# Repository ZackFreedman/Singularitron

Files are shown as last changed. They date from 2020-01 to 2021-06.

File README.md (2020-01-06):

# Singularitron
## Ridiculous VFD-equipped modular cyberwatch

More info at the [Singularitron's Hackaday.io page.](https://hackaday.io/project/169343-singularitron-modular-cyberwatch)

The Singularitron is a massive wrist-mounted wearable device with four expansion slots. Equip any combination of flashlight, laser, IR thermometer, environmental, and SD card modules, and stun the crowd with RGB buttons. The ultra-bright, extremely breakable VFD adds bright-daylight readability... and style.

Real talk, this does work, but is not intended to be a serious project. A VFD is a terrible choice for a wearable, and many parts of the project are suboptimal, ridiculous, and/or barely functional. Also, I made a bunch of boo-boos on the board and fixed them with airwires. I'll fix that some time, maybe.

That said, it serves its purpose - drawing attention at Meetups and conferences - really well. The cartridge form-factor is pretty cool, and this has neat super-small implementations of some interesting parts. Have fun!

If you really do want to build this, there are a lot of gotchas:

* I'll add them
* Eventually
* Right here

Copyright 2017 Zack Freedman

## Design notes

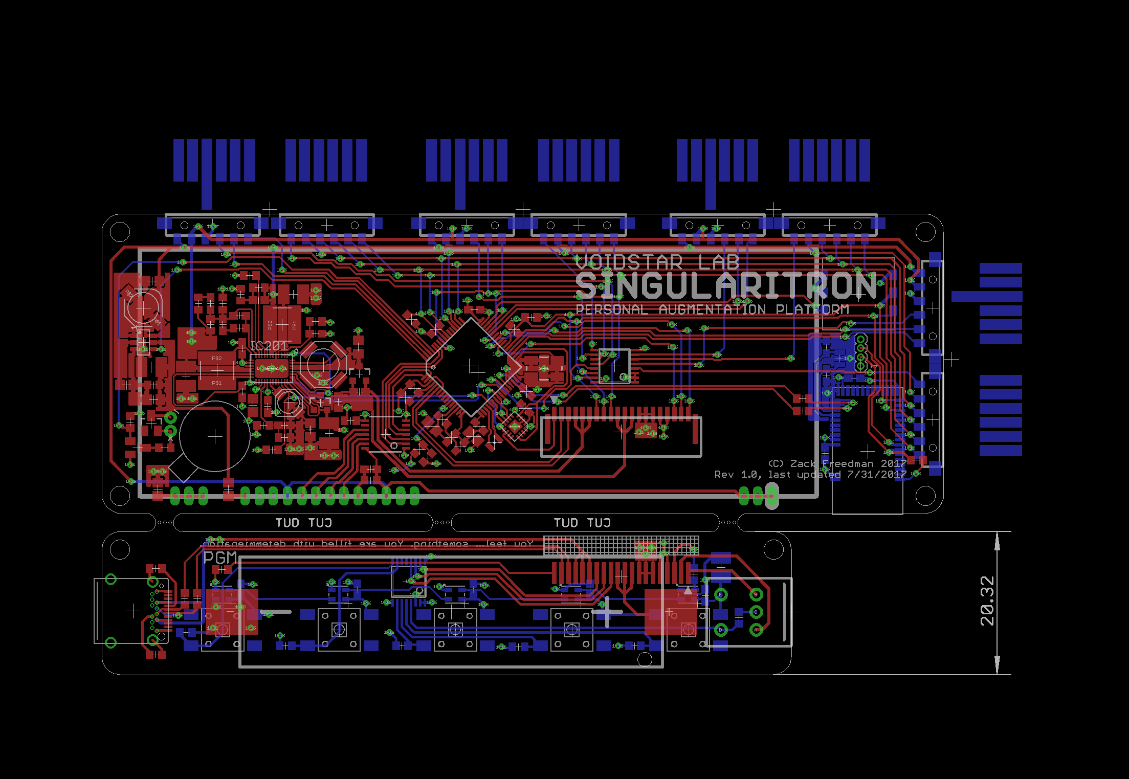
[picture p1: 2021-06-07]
Main PCB's/Singularitron Main Board Design.png

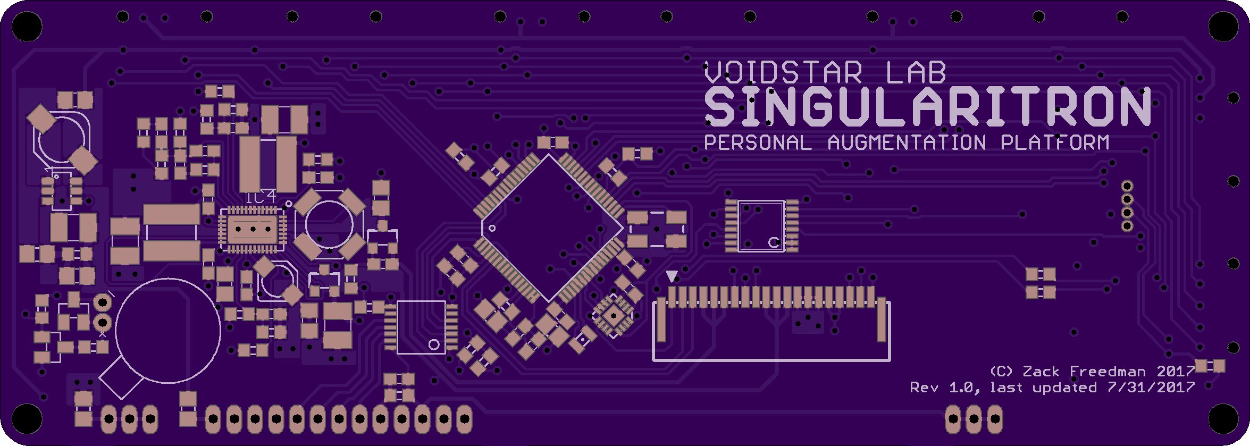
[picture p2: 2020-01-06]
Main PCB's/Singularitron 1B Mainboard Bottom Rendering.png

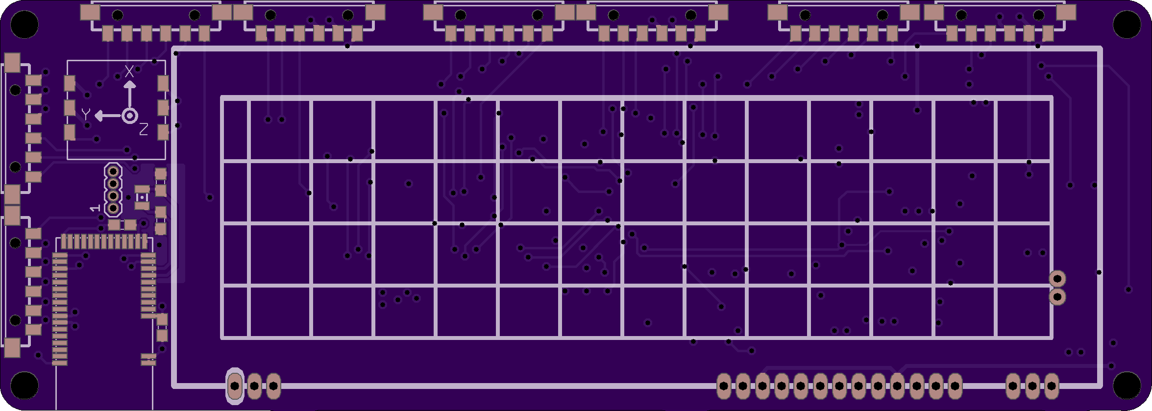
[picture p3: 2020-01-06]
Main PCB's/Singularitron 1B Main Board Rendering.png

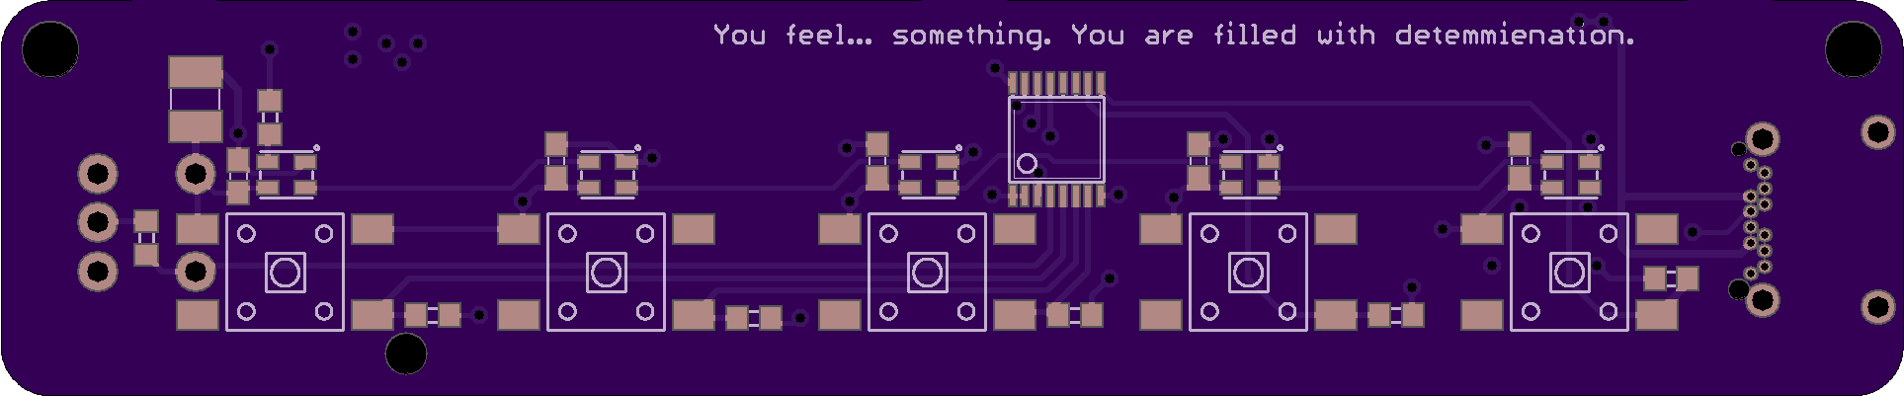
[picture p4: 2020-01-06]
Main PCB's/Singularitron 1B DB Top Rendering.png

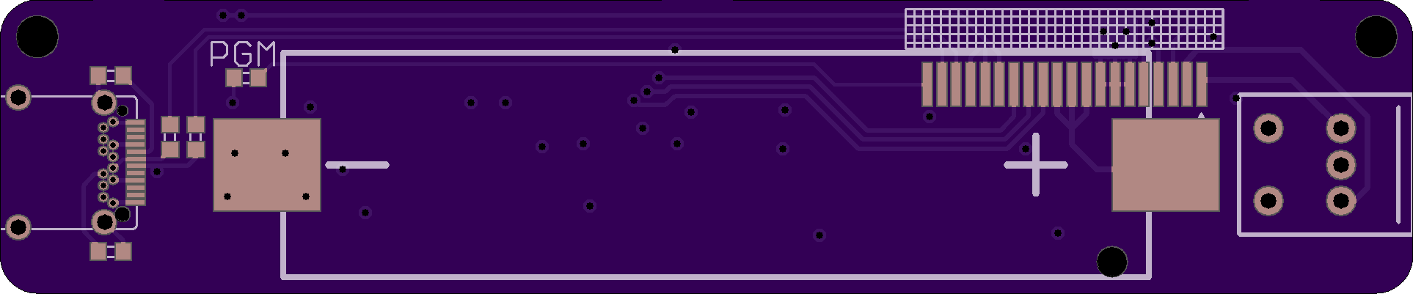
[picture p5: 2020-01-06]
Main PCB's/Singularitron 1B DB Bottom Rendering.png

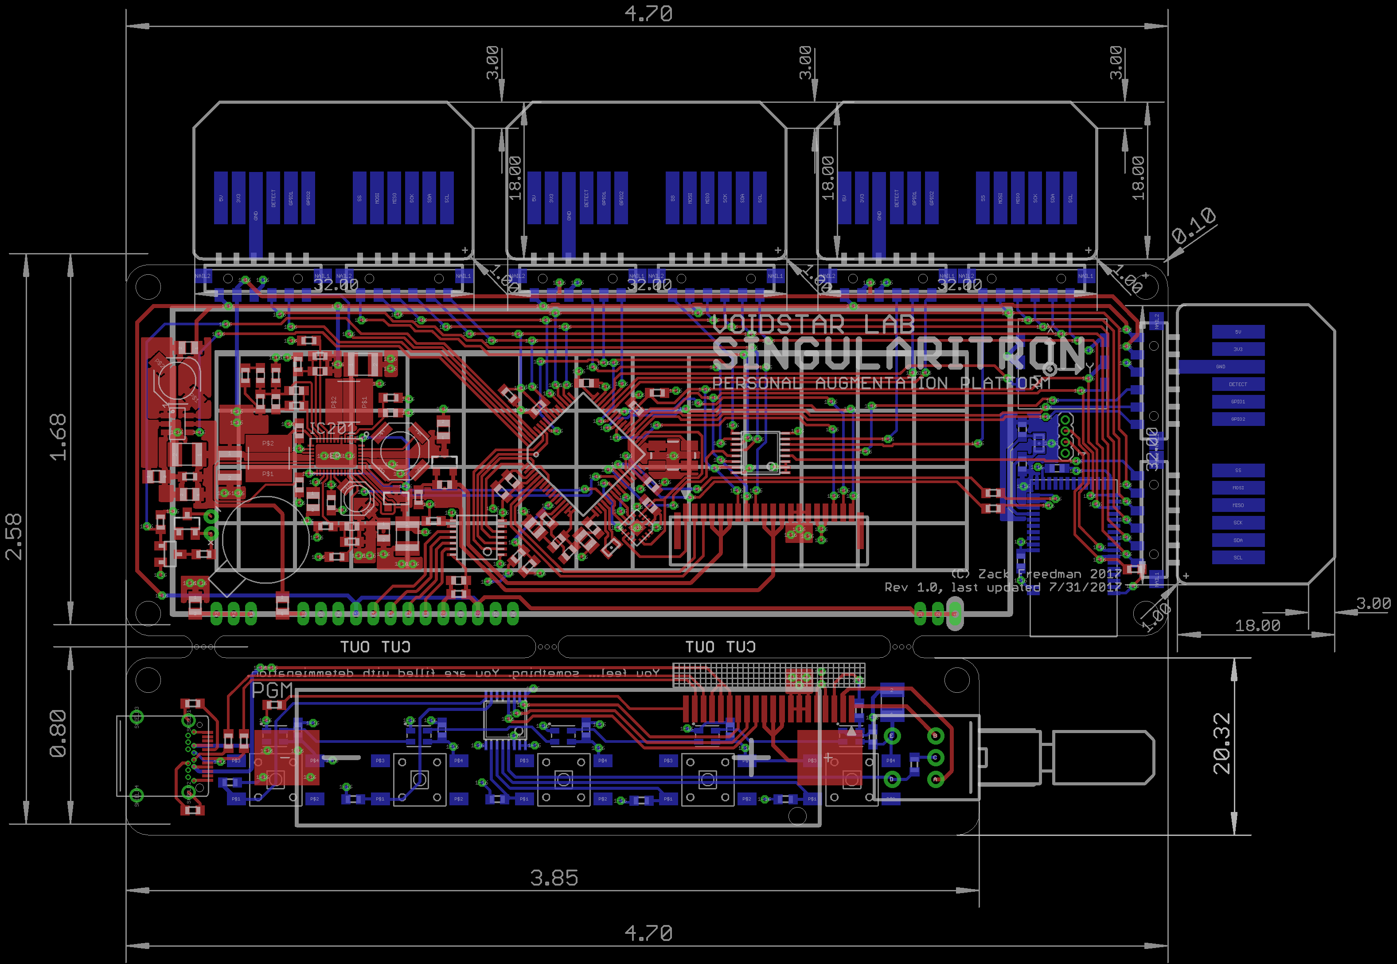
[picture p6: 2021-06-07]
Main PCB's/Singularitron Board.png

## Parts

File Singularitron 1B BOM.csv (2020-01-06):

Qty | Value | Device | Package | Parts | Description
1 |  | FFC_1MM_20POS_DIRECT | FFC_1MM_20POS_DIRECT | JP701 | 1mm-pitch, 20-position FFC glued and soldered directly to the PCB.
1 |  | M041.27MM | 1X04-1.27MM | JP401 | Header 4
1 |  | TXB0104PWR | TSSOP14 | U301 | 4-Bit Bi-Directional Level Shifter
1 | 0.01µF | C-USC0603 | C0603 | C301 | CAPACITOR, American symbol
12 | 0.1µF | C-USC0603 | C0603 | C213, C601, C602, C603, C604, C607, C608, C802, C803, C804, C805, C806 | CAPACITOR, American symbol
1 | 0.47µH | C-USC1210 | C1210 | C217 | CAPACITOR, American symbol
1 | 100nF | C-USC0603 | C0603 | C201 | CAPACITOR, American symbol
1 | 100Ω | R-US_R0603 | R0603 | R812 | RESISTOR, American symbol
2 | 105kΩ | R-US_R0603 | R0603 | R205, R215 | RESISTOR, American symbol
10 | 10kΩ | R-US_R0603 | R0603 | R207, R210, R301, R405, R806, R807, R808, R809, R810, R811 | RESISTOR, American symbol
1 | 10kΩ 0.1% 250mW | R-US_R0805 | R0805 | R213 | RESISTOR, American symbol
3 | 10pF | C-USC0603 | C0603 | C206, C207, C214 | CAPACITOR, American symbol
3 | 10µF | C-USC0805 | C0805 | C202, C203, C210 | CAPACITOR, American symbol
1 | 121kΩ | R-US_R0603 | R0603 | R216 | RESISTOR, American symbol
1 | 12401548E4#2A | 12401548E4#2A | 12401548E4#2A | CN801 | Amphenol USB C receptacle, surface-mount and through-hole pins
1 | 12kΩ | R-US_R0603 | R0603 | R401 | RESISTOR, American symbol
2 | 12pF | C-USC0603 | C0603 | C403, C404 | CAPACITOR, American symbol
1 | 15kΩ | R-US_R0603 | R0603 | R211 | RESISTOR, American symbol
1 | 16.9kΩ | R-US_R0603 | R0603 | R203 | RESISTOR, American symbol
1 | 16MHz | CRYSTAL-SHIELDED | CRYSTAL-SMD-5X3 | Y601
1 | 1MΩ | R-US_R0603 | R0603 | R801 | RESISTOR, American symbol
1 | 1kΩ | R-US_R0603 | R0603 | R208 | RESISTOR, American symbol
4 | 1µF | C-USC0603 | C0603 | C204, C205, C401, C402 | CAPACITOR, American symbol
1 | 1µF | C-USC0805 | C0805 | C212 | CAPACITOR, American symbol
3 | 2.2µF | C-USC0603 | C0603 | C211, C605, C606 | CAPACITOR, American symbol
2 | 2.2µH | CDRH4D22/HP | CDRH4D22/HP | L201, L205 | Sumida low-DCR shielded inductor
1 | 200kΩ | R-US_R0603 | R0603 | R302 | RESISTOR, American symbol
2 | 220Ω | R-US_R0603 | R0603 | R402, R403 | RESISTOR, American symbol
1 | 22pF | C-USC0805 | C0805 | C216 | CAPACITOR, American symbol
4 | 22µH | C-USC1210 | C1210 | C208, C209, C219, C801 | CAPACITOR, American symbol
1 | 22µH | SUMIDA_CDPH4D19F | CDPH4D19F | L204 | Low-profile shielded inductor, proprietary footprint, useful for low-current switching regulators
1 | 22Ω | R-US_R0603 | R0603 | R404 | RESISTOR, American symbol
1 | 22Ω 1/2W? | R-US_R0805 | R0805 | R303 | RESISTOR, American symbol
1 | 280kΩ 0.1% | R-US_R0603 | R0603 | R212 | RESISTOR, American symbol
1 | 3.01kΩ | R-US_R0603 | R0603 | R209 | RESISTOR, American symbol
1 | 3.3µH | CDRH6D12 | CDRH6D12 | L202 | Sumida low-profile shielded inductor
1 | 3.61kΩ | R-US_R0603 | R0603 | R206 | RESISTOR, American symbol
2 | 324kΩ | R-US_R0603 | R0603 | R204, R214 | RESISTOR, American symbol
1 | 32kHz | FC-12M | FC-12M | Q401 | kHz RANGE CRYSTAL UNIT
1 | 32kHz 12pF | FC-12M | FC-12M | Q601 | kHz RANGE CRYSTAL UNIT
1 | 330pF | C-USC0603 | C0603 | C215 | CAPACITOR, American symbol
1 | 33pF | C-USC0603 | C0603 | C218 | CAPACITOR, American symbol
2 | 33Ω | R-US_R0603 | R0603 | R803, R804 | RESISTOR, American symbol
4 | 4.7kΩ | R-US_R0603 | R0603 | R602, R603, R604, R605 | RESISTOR, American symbol
1 | 4.7µH | CDRH3D16/HP | CDRH3D16/HP | L203 | Sumida miniature low-profile shielded inductor
1 | 40kΩ | R-US_R0603 | R0603 | R201 | RESISTOR, American symbol
1 | 470Ω | R-US_R0603 | R0603 | R601 | RESISTOR, American symbol
2 | 5.1kΩ | R-US_R0603 | R0603 | R802, R805 | RESISTOR, American symbol
1 | 6.2Ω 1/2W | R-US_R0805 | R0805 | R304 | RESISTOR, American symbol
2 | 600Ω@100MHz | FERRITE-0603 | FB603 | L601, L602 | Ferrite bead in various packages
1 | 88.7kΩ | R-US_R0603 | R0603 | R202 | RESISTOR, American symbol
8 | AVX_9155066 | AVX_9155066 | 9155006 | CN501, CN502, CN503, CN504, CN505, CN506, CN507, CN508 | AVX 6-position 2mm pitch right-angle battery connector
1 | BAT54C | BAT54C | SOT23 | D401 | Schottky Diodes
1 | DS2045 | DS2045 | DS2045 | DISPLAY301
1 | EM7180SFP | EM7180SFP | EM7180SFP | MOD402 | EM7180SFP Sensor fusion platform module. Incorporated EM7180 Sentral Hub coprocessor, Bosch BMX055 9-DOF IMU, and ST24256 32KB EEPROM.
1 | HFW20R-1ST | HFW20R-1ST | HFW20R-1STE1LF | CN701 | Amphenol HF20R 20-contact 1mm-pitch FFC/FPC connector. No locking feature - friction only.
1 | KEYSTONE_1024 | KEYSTONE_1024 | KEYSTONE-1024-PROVISIONAL | BAT801
1 | LT3461A | LT3461A | SOT-23 | IC202 | Linear Technologies LT3461A 3MHz boost regulator, 16V max VIN, 38V max VOUT, 70mA output load current
1 | LTC3586-3 | LTC3586-3 | QFN-38_EP_UFE | IC201 | Linear LTC3586 PMIC
1 | MDBT40 | MDBT40 | MDBT40 | MOD401
1 | MK20DX128VLH5 | MK20DX128VLH5 | MK20DX128VLH5 | U601 | Teensy 3.0 Processing Unit - MK20DX128VLH5 ARM Cortex M0
1 | MKL02Z32VFG4 | MKL02Z32VFG4 | QFN16-3X3 | IC601
1 | MOTOR10MM | MOTOR10MM | VIBE-MOTOR-10MM | MOTOR401 | Vibration Motor- ROB-08449
5 | NEOPIXEL_NANO_2427 | NEOPIXEL_NANO_2427 | SK6805-2427 | LED801, LED802, LED803, LED804, LED805
1 | NVR4003NT3G | MOSFET-NREFLOW | SOT23 | Q402 | N-Channel Mosfet
2 | PCA9534PW | PCA9534PW | TSSOP16 | IC501, IC801 | 8-bit I2C-bus and SMBus low power I/O port with interrupt
1 | PEC09 | PEC09 | PEC09-2X20X-TXXXX | SW806 | Bourns low-profile rotary encoders
2 | SI2333DS-T1-E3 | MOSFET-PCHANNELSMD | SOT23-3 | Q201, Q202 | Generic PMOSFET
4 | SINGULARITRON_CART_BASE | SINGULARITRON_CART_BASE | SINGULARITRON_CART_BASE | JP501, JP502, JP503, JP504
5 | TACTILE_SWITCHTL3301-G | TACTILE_SWITCHTL3301-G | TL3301-X-FXXX-X-G | SW801, SW802, SW803, SW804, SW805

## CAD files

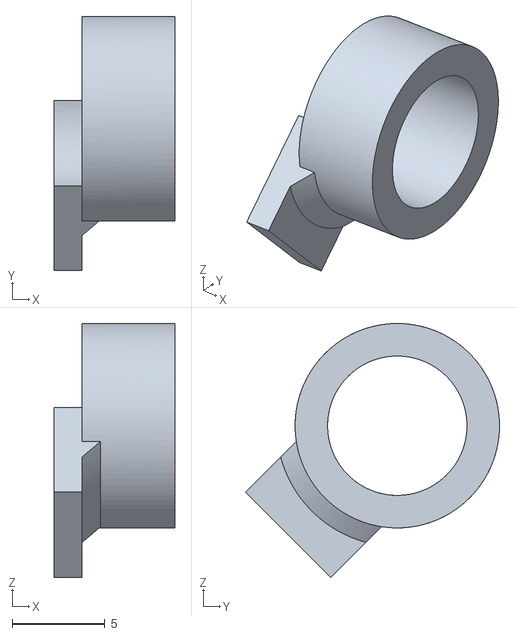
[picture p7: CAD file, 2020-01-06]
Enclosure/STL's/Singularitron Encoder Sleeve.stl
6.50 x 13.7 x 13.7

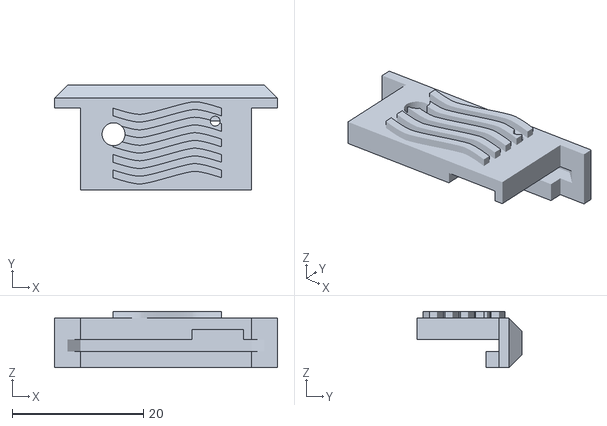
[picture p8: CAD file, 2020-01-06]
Modules/Enviro-Module/EnviroModule.stl
34.0 x 16.0 x 8.60

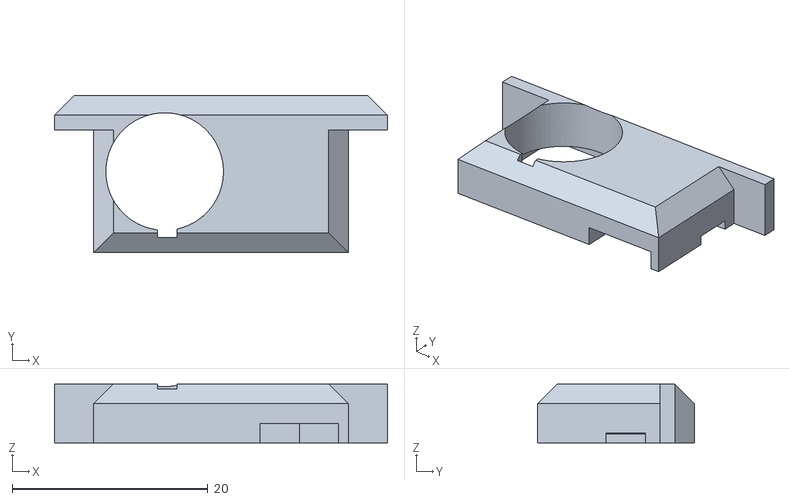
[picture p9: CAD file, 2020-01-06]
Modules/Flashlight Module/Flashlight Front.stl
34.0 x 16.0 x 6.00

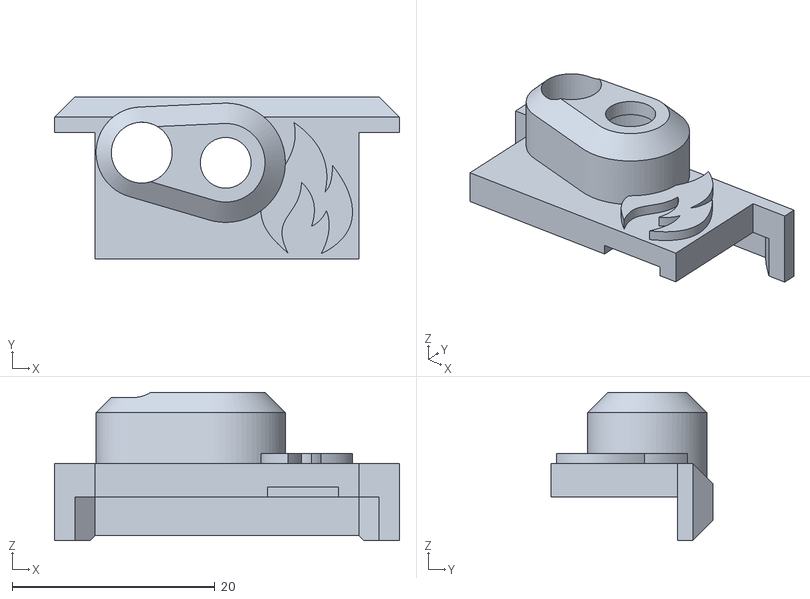
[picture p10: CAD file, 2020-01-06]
Modules/IR Thermometer Module/Thermodule.stl
34.0 x 16.0 x 14.6

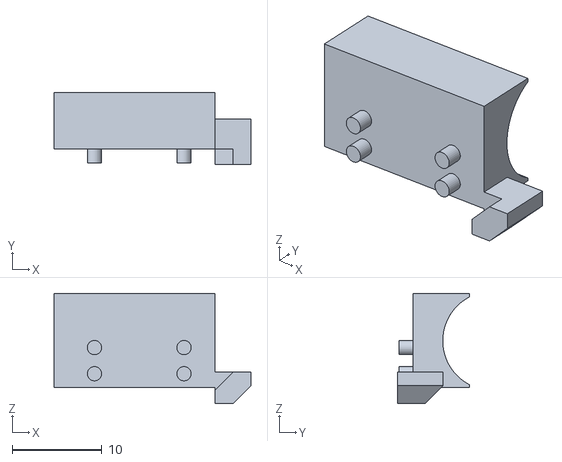
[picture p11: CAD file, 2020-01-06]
Modules/Laser Module/Laser Brace.stl
22.0 x 8.08 x 12.3

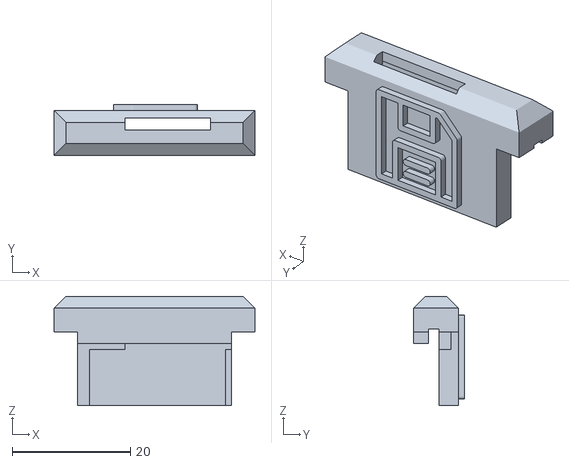
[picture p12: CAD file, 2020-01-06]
Modules/SD Card Module/SD Module.stl
34.0 x 8.60 x 18.5

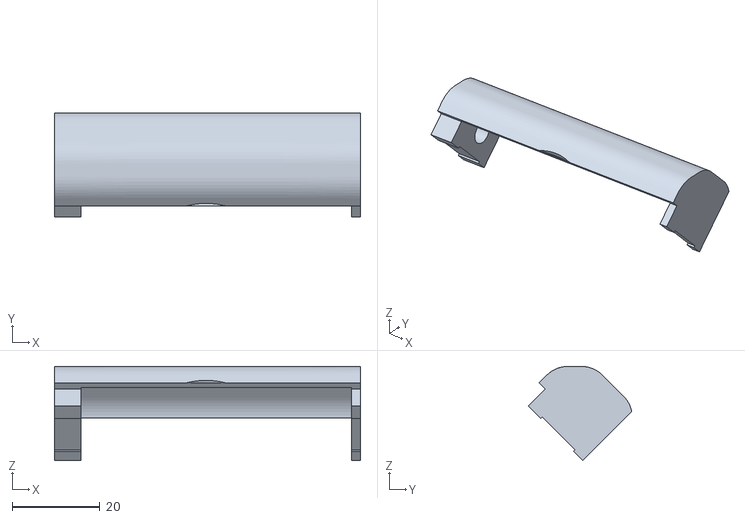
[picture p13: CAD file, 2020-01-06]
Enclosure/STL's/Singularitron Battery Lid.stl
69.8 x 23.6 x 21.5

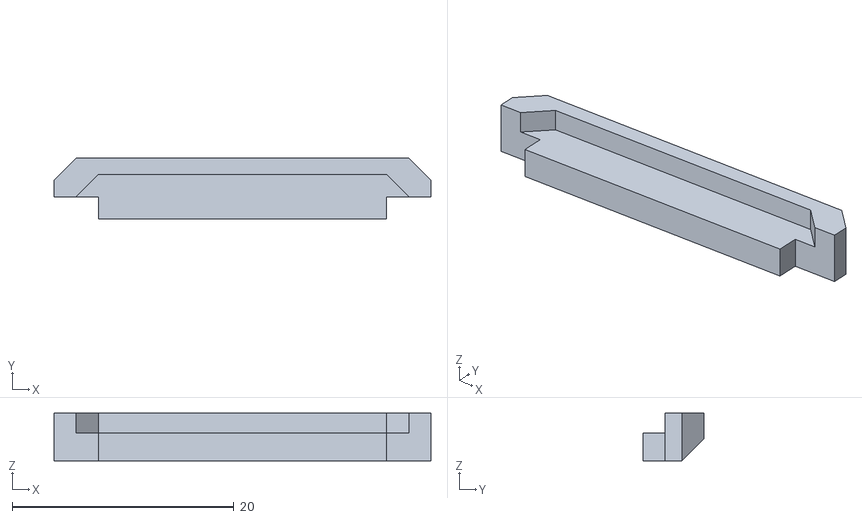
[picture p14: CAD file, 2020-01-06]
Modules/Flashlight Module/Flashlight Top.stl
34.0 x 5.50 x 4.30

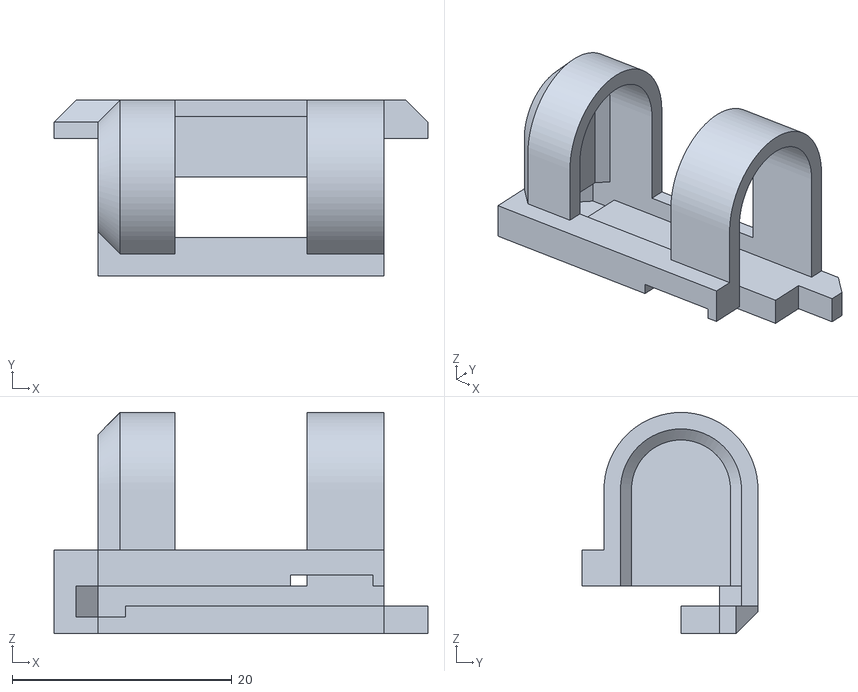
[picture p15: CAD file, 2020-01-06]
Modules/Laser Module/Laser Frame.stl
34.0 x 16.0 x 20.1

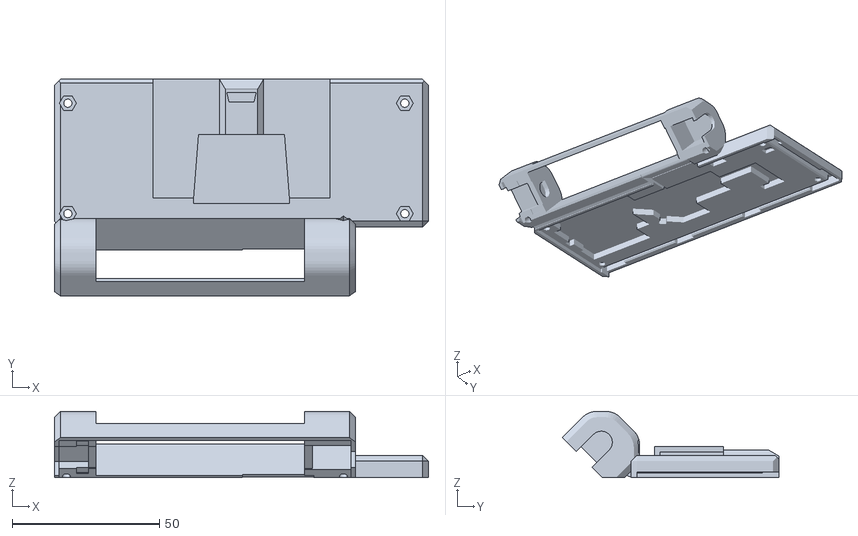
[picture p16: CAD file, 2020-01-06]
Enclosure/STL's/Singularitron Bottom.stl
126.9 x 73.5 x 22.5

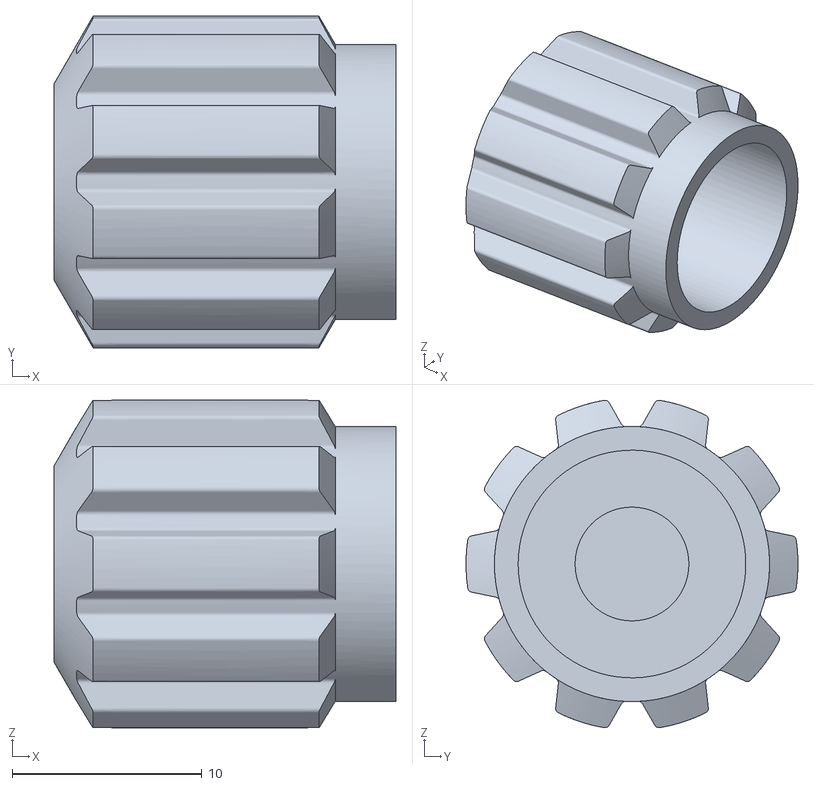
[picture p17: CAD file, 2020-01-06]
Enclosure/STL's/Singularitron Knob.stl
18.0 x 17.5 x 17.3

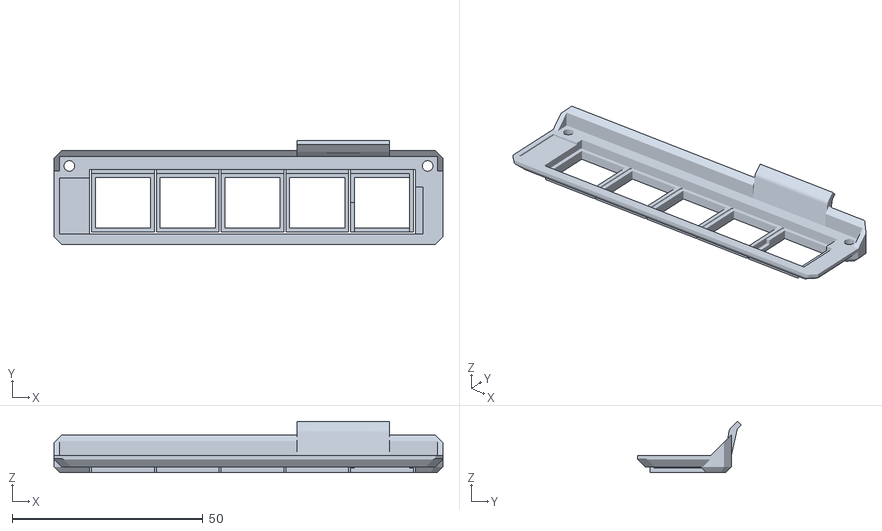
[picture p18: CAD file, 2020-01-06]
Enclosure/STL's/Singularitron Buttons.stl
102.1 x 27.2 x 13.5

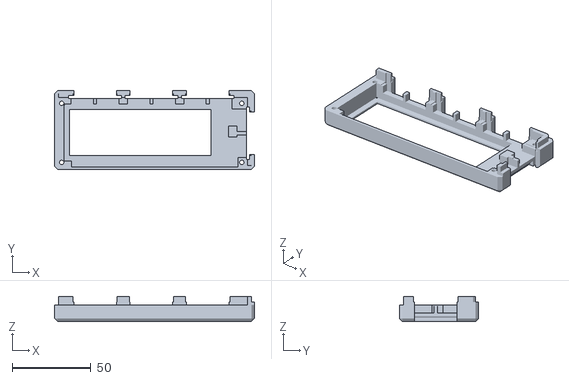
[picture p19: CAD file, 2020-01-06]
Enclosure/STL's/Singularitron Top.stl
126.9 x 50.2 x 16.0

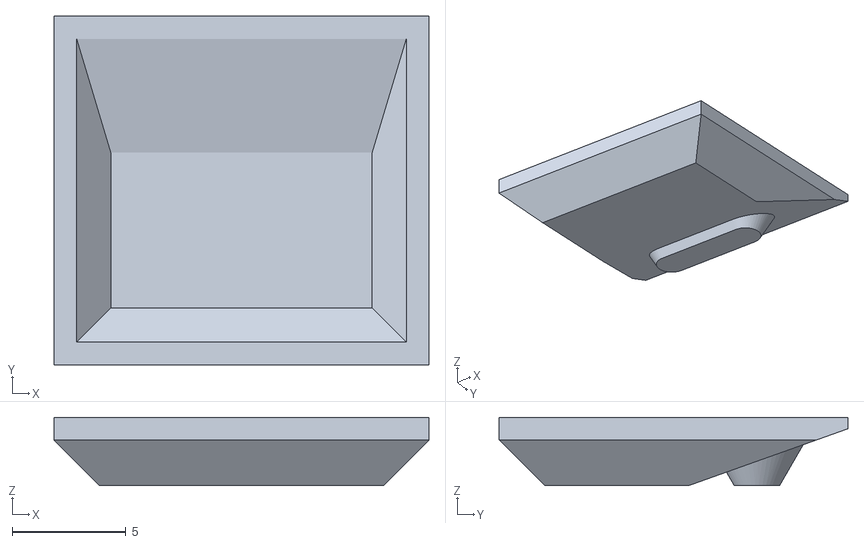
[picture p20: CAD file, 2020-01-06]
Enclosure/STL's/Keycap 0.stl
16.5 x 15.3 x 3.00

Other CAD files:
Enclosure/STL's/Keycap 1.stl
Enclosure/STL's/Keycap 2.stl
Enclosure/STL's/Keycap 3.stl
Enclosure/STL's/Keycap 4.stl
Enclosure/Overly Detailed Board Mockup.f3d
Enclosure/Singularitron Main.f3d
Modules/Enviro-Module/Enviro Module Cover Plate.f3d
Modules/Flashlight Module/Flashlight Module Cover Plate.f3d
Modules/IR Thermometer Module/Thermodule Cover.f3d
Modules/Laser Module/Laser Module Cover.f3d
Modules/SD Card Module/SD Module Cover Plate.f3d

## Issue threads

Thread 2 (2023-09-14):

Hola soy de latam

Aleemik, 2023-09-14:
Me encanta tu producto, aunque que es muy bobo, y poco fiable creo que sería genial tener uno en mi brazo, es demasiado increíble para muchas personas, compraría uno.

Sería genial que algún día lo vendas como un juguete curioso yo lo compraría. Estoy a la espera saludos y suerte.
Att Ale de Lima, Perú

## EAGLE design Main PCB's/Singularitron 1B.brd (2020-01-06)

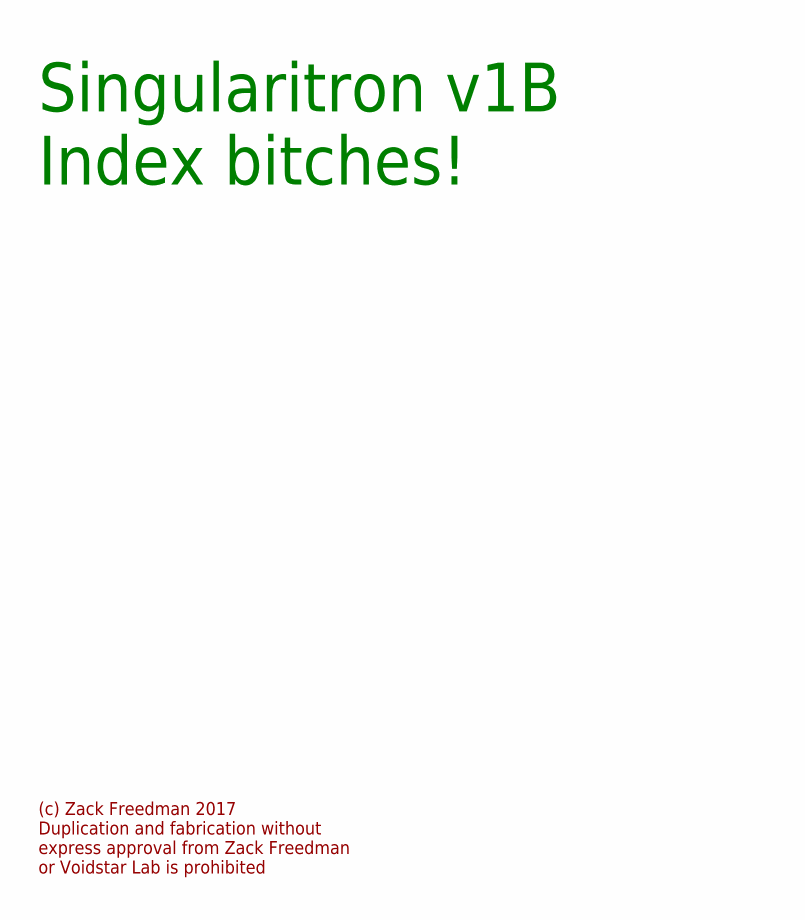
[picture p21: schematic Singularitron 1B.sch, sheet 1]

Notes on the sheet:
Singularitron v1B Index bitches!
(c) Zack Freedman 2017 Duplication and fabrication without express approval from Zack Freedman or Voidstar Lab is prohibited

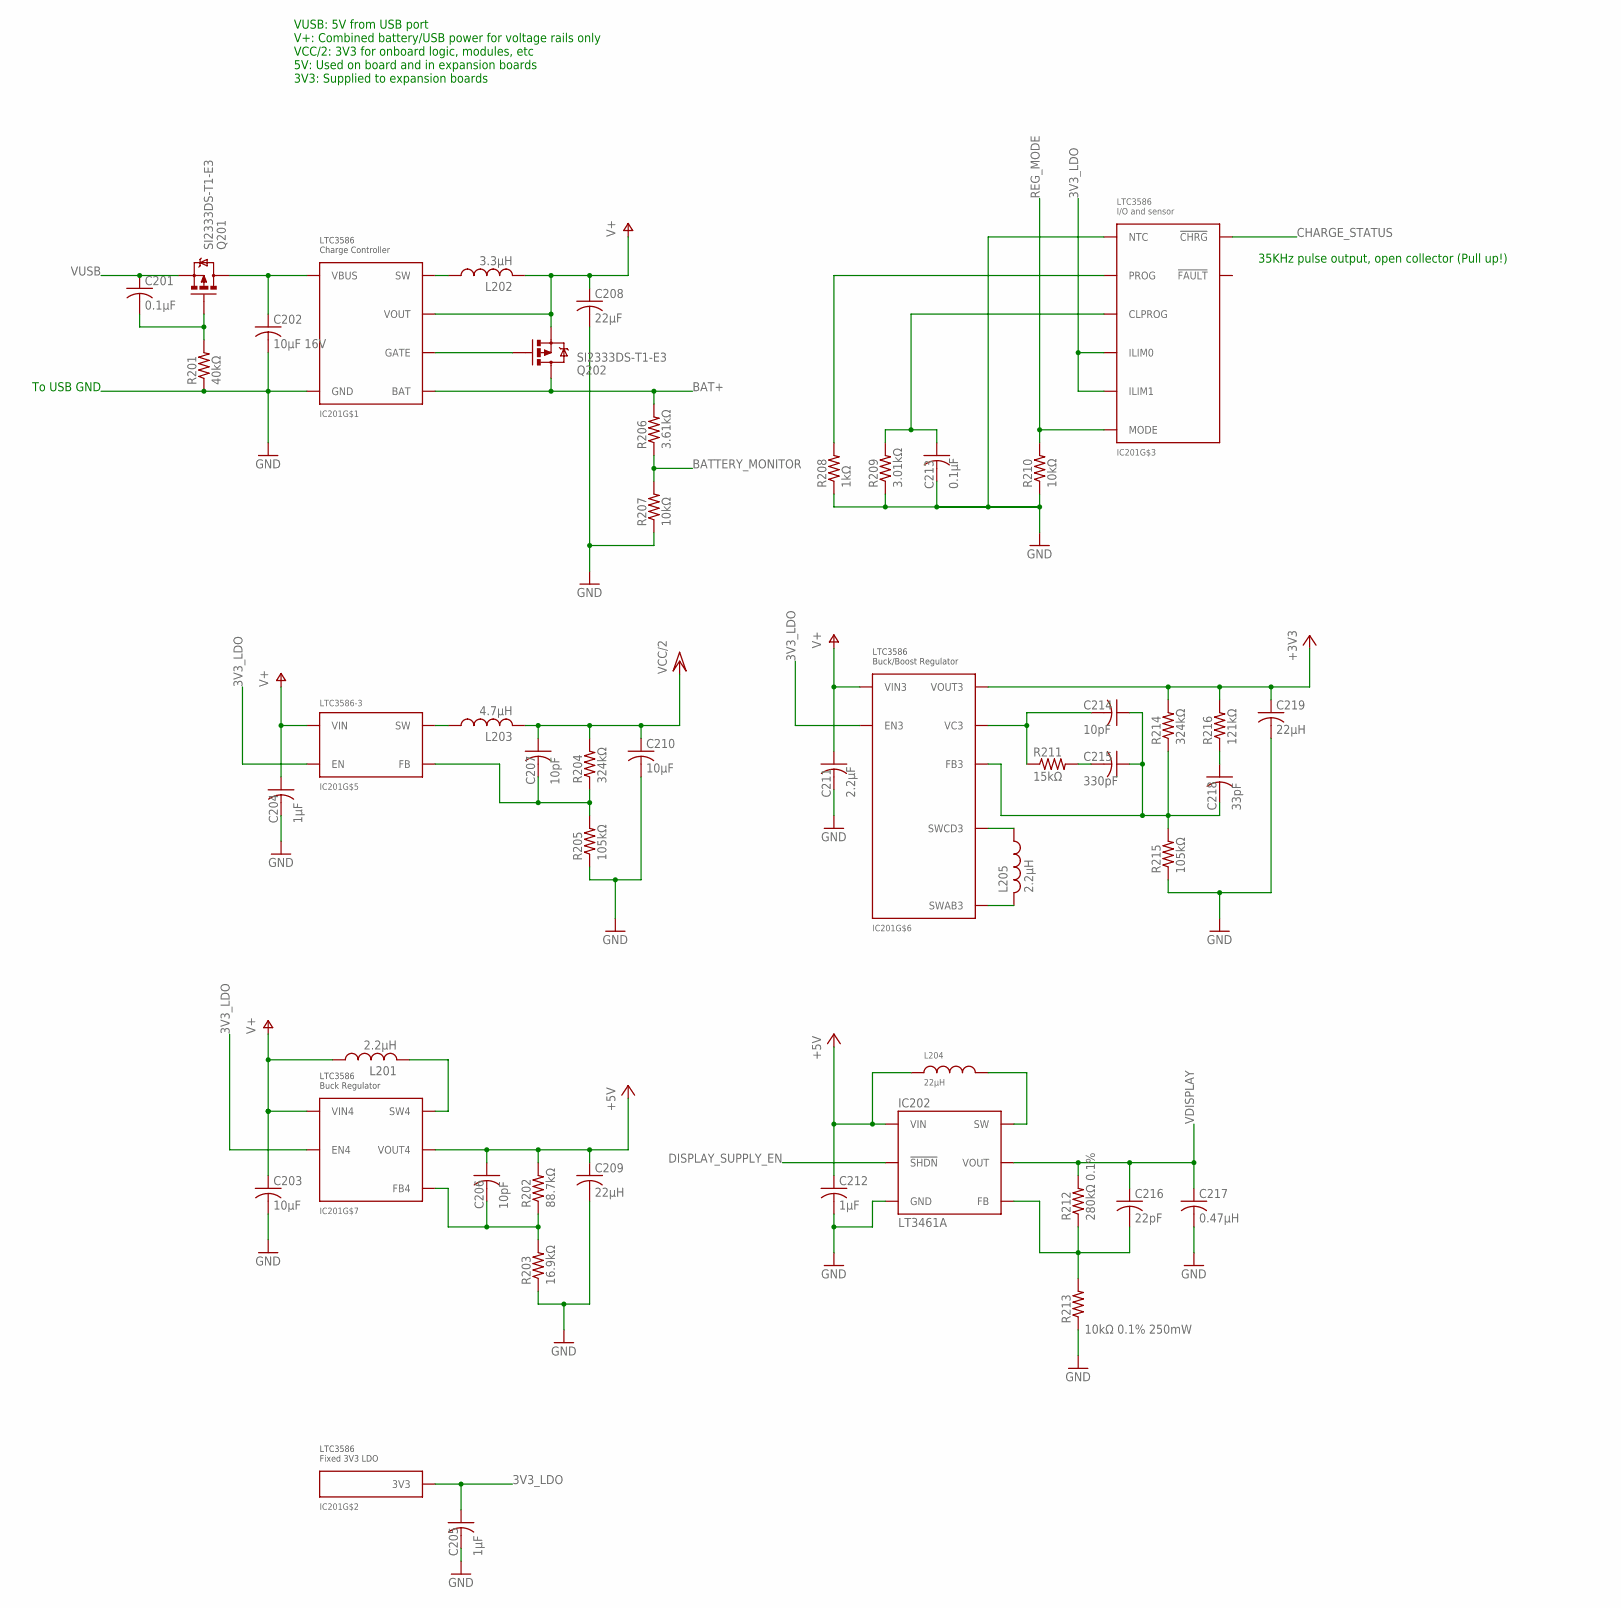
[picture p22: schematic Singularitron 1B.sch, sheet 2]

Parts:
C201, C213: 0.1µF; C0603
C202: 10µF 16V; C0805
C203, C210: 10µF; C0805
C204, C205: 1µF; C0603
C206, C207, C214: 10pF; C0603
C208: 22µF; C1210
C209, C219: 22µH; C1210
C211: 2.2µF; C0603
C212: 1µF; C0805
C215: 330pF; C0603
C216: 22pF; C0805
C217: 0.47µH; C1210
C218: 33pF; C0603
IC201: LTC3586-3; QFN-38_EP_UFE
IC202: LT3461A; SOT-23
L201, L205: 2.2µH; CDRH4D22/HP
L202: 3.3µH; CDRH6D12
L203: 4.7µH; CDRH3D16/HP
L204: 22µH; CDPH4D19F
Q201, Q202: SI2333DS-T1-E3; SOT23-3
R201: 40kΩ; R0603
R202: 88.7kΩ; R0603
R203: 16.9kΩ; R0603
R204, R214: 324kΩ; R0603
R205, R215: 105kΩ; R0603
R206: 3.61kΩ; R0603
R207, R210: 10kΩ; R0603
R208: 1kΩ; R0603
R209: 3.01kΩ; R0603
R211: 15kΩ; R0603
R212: 280kΩ 0.1%; R0603
R213: 10kΩ 0.1% 250mW; R0805
R216: 121kΩ; R0603

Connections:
3V3_LDO: C205.1, IC201.P$1 (ILIM0), IC201.P$2 (ILIM1), IC201.P$3 (3V3), IC201.P$18 (EN3), IC201.P$20 (EN), IC201.P$33 (EN4); also elsewhere on the board
+3V3: C219.1, IC201.P$16 (VOUT3), IC201.P$17 (VOUT3), R214.2, R216.2; also elsewhere on the board
+5V: C206.1, C209.1, C212.1, IC201.P$6 (VOUT4), IC201.P$7 (VOUT4), IC202.P6 (VIN), L204.P$1, R202.2; also elsewhere on the board
BAT+: IC201.P$32 (BAT), Q202.3 (D), R206.2; also elsewhere on the board
BATTERY_MONITOR: R206.1, R207.2; also elsewhere on the board
CHARGE_STATUS: IC201.P$30 (!CHRG); also elsewhere on the board
CLPROG: C213.1, IC201.P$4 (CLPROG), R209.2
DISPLAY_SUPPLY_EN: IC202.P4 (!SHDN); also elsewhere on the board
GND: C202.2, C203.2, C204.2, C205.2, C208.2, C209.2, C210.2, C211.2, C212.2, C213.2, C217.2, C219.2, IC201.EP (GND), IC201.P$5 (NTC), IC202.P2 (GND), R201.1, R203.1, R205.1, R207.1, R208.1, R209.1, R210.1, R213.1, R215.1; also elsewhere on the board
unnamed: C202.1, IC201.P$35 (VBUS), IC201.P$36 (VBUS), Q201.3 (D)
unnamed: IC201.P$37 (SW), L202.P$1 (1)
unnamed: C201.2, Q201.1 (G), R201.2
unnamed: IC201.P$31 (GATE), Q202.1 (G)
unnamed: IC201.P$25 (SW), L203.P$1 (1)
unnamed: IC201.P$29 (PROG), R208.2
unnamed: C207.2, IC201.P$23 (FB), R204.1, R205.2
unnamed: IC202.P1 (SW), L204.P$2
unnamed: C214.2, IC201.P$12 (VC3), R211.1
unnamed: C216.2, IC202.P3 (FB), R212.1, R213.2
unnamed: C215.2, R211.2
unnamed: IC201.P$8 (SW4), L201.P$2 (2)
unnamed: C218.1, R216.1
unnamed: C206.2, IC201.P$10 (FB4), R202.1, R203.2
unnamed: C214.1, C215.1, C218.2, IC201.P$11 (FB3), R214.1, R215.2
unnamed: IC201.P$19 (SWCD3), L205.P$1 (1)
unnamed: IC201.P$13 (SWAB3), L205.P$2 (2)
REG_MODE: IC201.P$9 (MODE), R210.2
V+: C203.1, C204.1, C208.1, C211.1, IC201.P$14 (VIN3), IC201.P$15 (VIN3), IC201.P$22 (VIN4), IC201.P$24 (VIN), IC201.P$34 (VOUT), L201.P$1 (1), L202.P$3 (2), Q202.2 (S)
VCC/2: C207.1, C210.1, L203.P$2 (2), R204.2; also elsewhere on the board
VDISPLAY: C216.1, C217.1, IC202.P5 (VOUT), R212.2; also elsewhere on the board
VUSB: C201.1, Q201.2 (S); also elsewhere on the board

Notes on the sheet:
To USB GND
VUSB: 5V from USB port V+: Combined battery/USB power for voltage rails only VCC/2: 3V3 for onboard logic, modules, etc 5V: Used on board and in expansion boards 3V3: Supplied to expansion boards
35KHz pulse output, open collector (Pull up!)

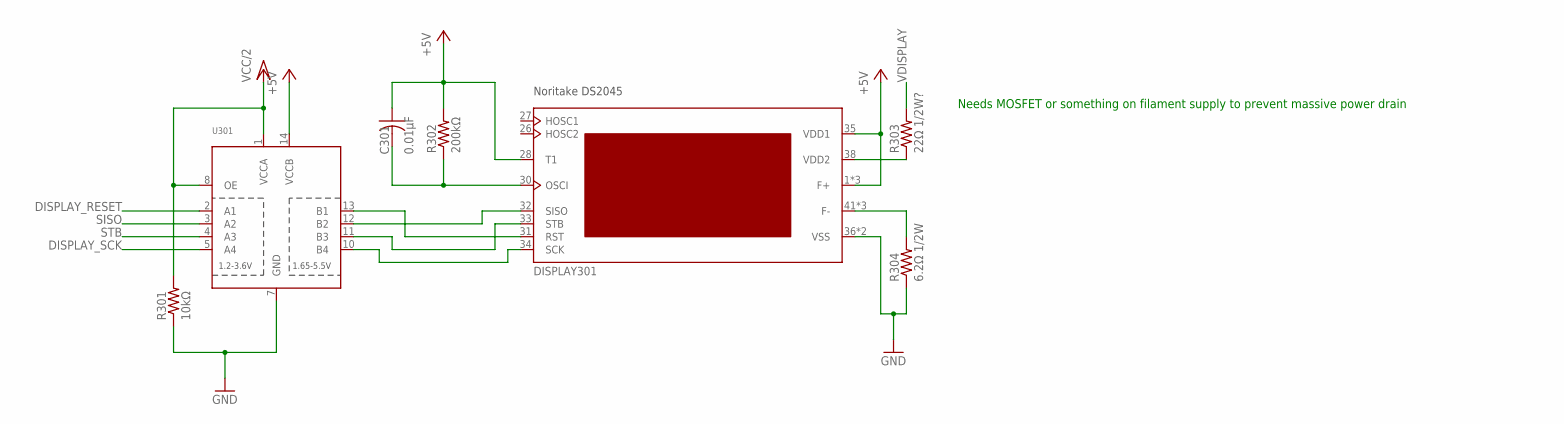
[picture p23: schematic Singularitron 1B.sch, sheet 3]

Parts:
C301: 0.01µF; C0603
DISPLAY301: DS2045
R301: 10kΩ; R0603
R302: 200kΩ; R0603
R303: 22Ω 1/2W?; R0805
R304: 6.2Ω 1/2W; R0805
U301: TXB0104PWR; TSSOP14

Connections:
+5V: C301.1, DISPLAY301.1 (F+), DISPLAY301.2 (F+), DISPLAY301.3 (F+), DISPLAY301.28 (T1), DISPLAY301.35 (VDD1), R302.2, U301.14 (VCCB); also elsewhere on the board
DISPLAY_RESET: U301.2 (A1); also elsewhere on the board
DISPLAY_SCK: U301.5 (A4); also elsewhere on the board
GND: DISPLAY301.36 (VSS), DISPLAY301.37 (VSS), R301.1, R304.1, U301.7 (GND); also elsewhere on the board
unnamed: DISPLAY301.31 (RST), U301.13 (B1)
unnamed: DISPLAY301.38 (VDD2), R303.1
unnamed: DISPLAY301.41 (F-), DISPLAY301.42 (F-), DISPLAY301.43 (F-), R304.2
unnamed: DISPLAY301.32 (SISO), U301.12 (B2)
unnamed: DISPLAY301.33 (STB), U301.11 (B3)
unnamed: DISPLAY301.34 (SCK), U301.10 (B4)
unnamed: C301.2, DISPLAY301.30 (OSCI), R302.1
SISO: U301.3 (A2); also elsewhere on the board
STB: U301.4 (A3); also elsewhere on the board
VCC/2: R301.2, U301.1 (VCCA), U301.8 (OE); also elsewhere on the board
VDISPLAY: R303.2; also elsewhere on the board

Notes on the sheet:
Needs MOSFET or something on filament supply to prevent massive power drain

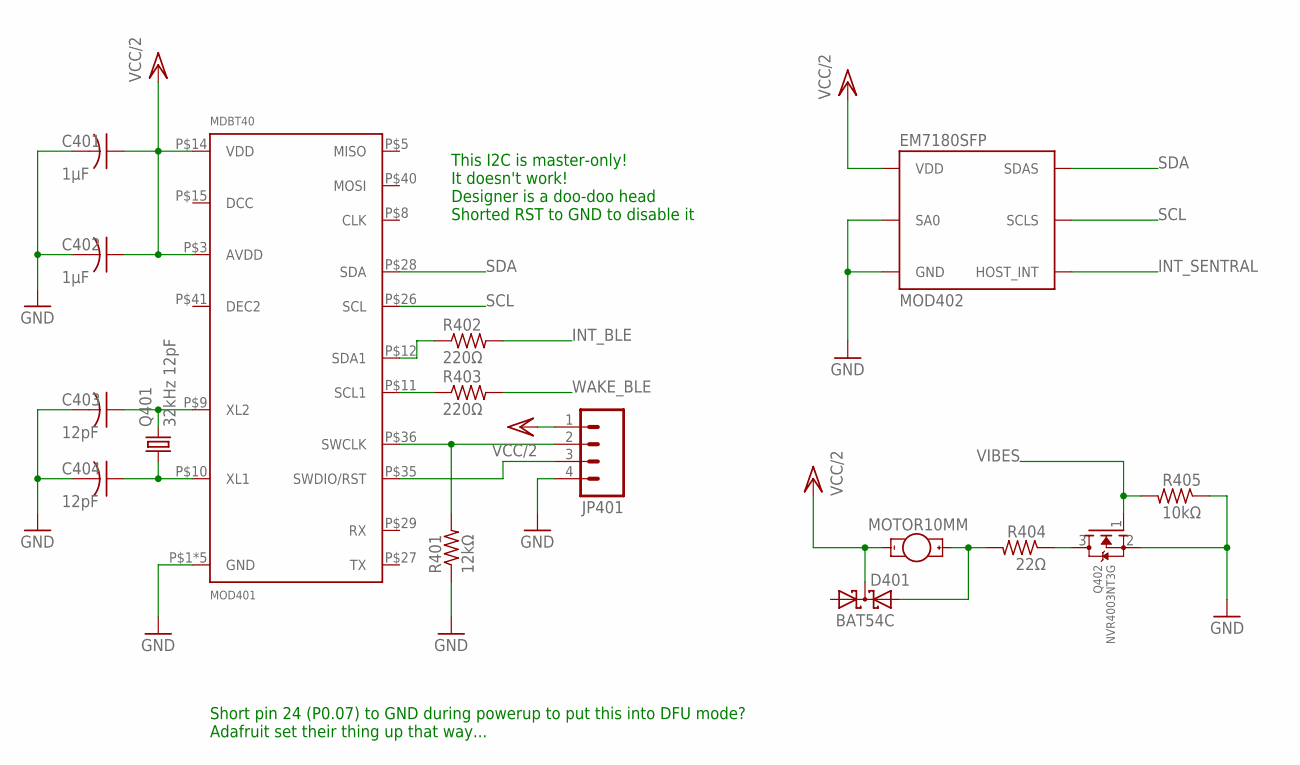
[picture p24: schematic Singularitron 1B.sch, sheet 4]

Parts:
C401, C402: 1µF; C0603
C403, C404: 12pF; C0603
D401: BAT54C; SOT23
JP401: M041.27MM; 1X04-1.27MM
MOD401: MDBT40
MOD402: EM7180SFP
MOTOR401: MOTOR10MM; VIBE-MOTOR-10MM
Q401: 32kHz 12pF; FC-12M
Q402: NVR4003NT3G; SOT23
R401: 12kΩ; R0603
R402, R403: 220Ω; R0603
R404: 22Ω; R0603
R405: 10kΩ; R0603

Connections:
GND: C401.2, C402.2, C403.2, C404.2, JP401.4, MOD401.P$1 (GND), MOD401.P$2 (GND), MOD401.P$13 (GND), MOD401.P$25 (GND), MOD401.P$42 (GND), MOD402.P$5 (SA0), MOD402.P$6 (GND), Q402.2 (S), R401.1, R405.1; also elsewhere on the board
INT_BLE: R402.2; also elsewhere on the board
INT_SENTRAL: MOD402.P$4 (HOST_INT); also elsewhere on the board
unnamed: MOD401.P$12 (SDA1), R402.1
unnamed: D401.2 (A2), MOTOR401.+, R404.2
unnamed: MOD401.P$11 (SCL1), R403.1
unnamed: Q402.3 (D), R404.1
unnamed: C404.1, MOD401.P$10 (XL1), Q401.1
unnamed: C403.1, MOD401.P$9 (XL2), Q401.2
unnamed: JP401.2, MOD401.P$36 (SWCLK), R401.2
unnamed: JP401.3, MOD401.P$35 (SWDIO/RST)
SCL: MOD401.P$26 (SCL), MOD402.P$3 (SCLS); also elsewhere on the board
SDA: MOD401.P$28 (SDA), MOD402.P$2 (SDAS); also elsewhere on the board
VCC/2: C401.1, C402.1, D401.3 (CC), JP401.1, MOD401.P$3 (AVDD), MOD401.P$14 (VDD), MOD402.P$1 (VDD), MOTOR401.-; also elsewhere on the board
VIBES: Q402.1 (G), R405.2; also elsewhere on the board
WAKE_BLE: R403.2; also elsewhere on the board

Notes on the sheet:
This I2C is master-only! It doesn't work! Designer is a doo-doo head Shorted RST to GND to disable it
Short pin 24 (P0.07) to GND during powerup to put this into DFU mode? Adafruit set their thing up that way...

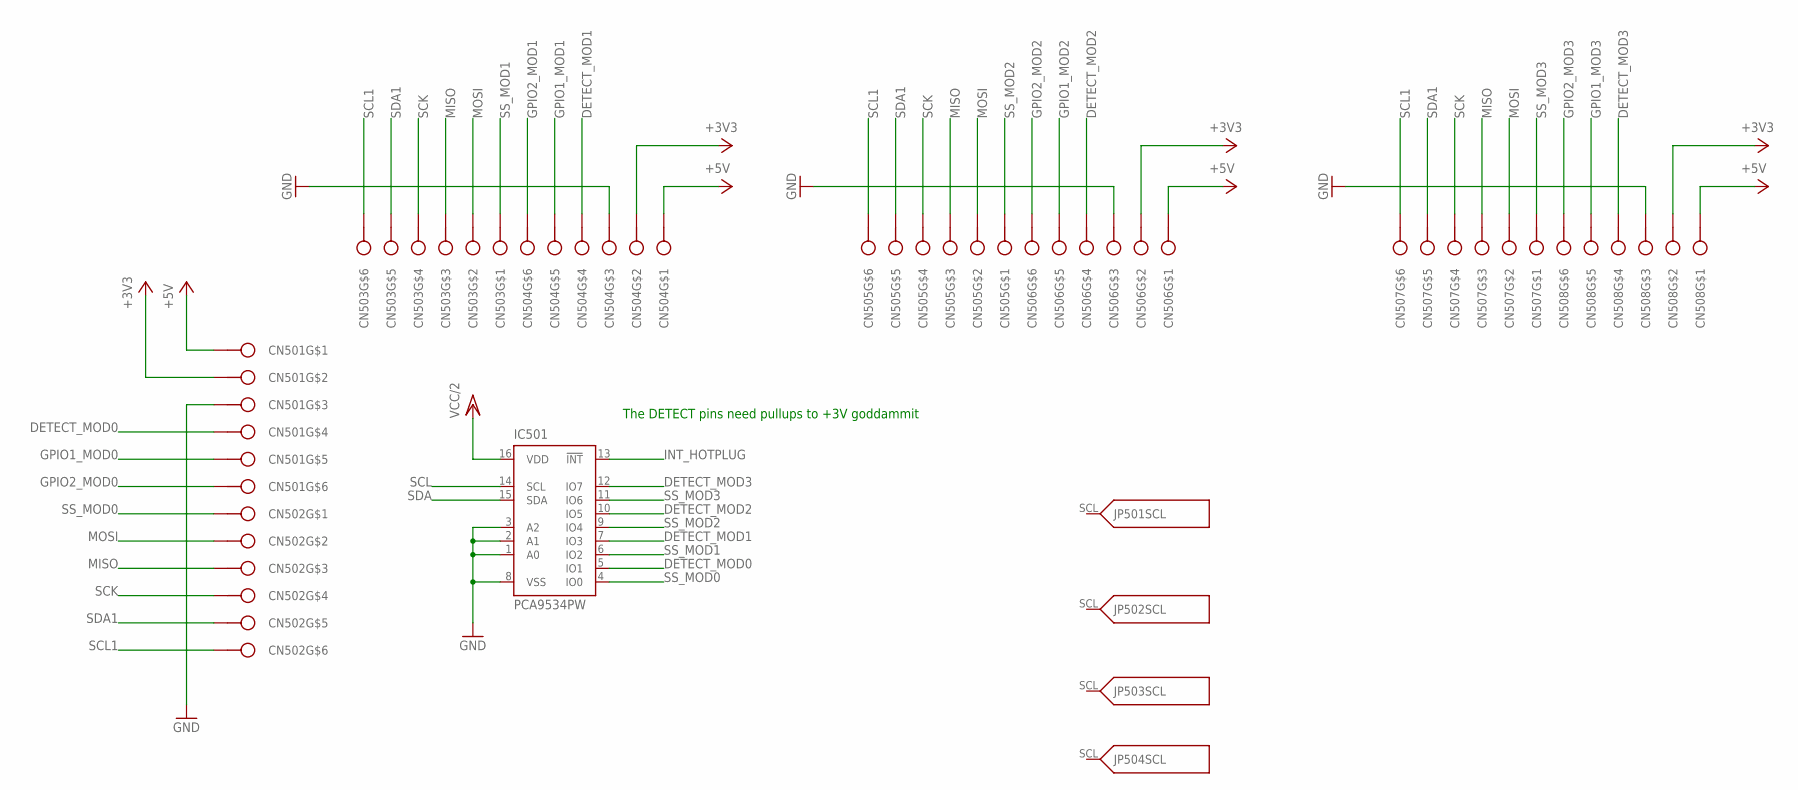
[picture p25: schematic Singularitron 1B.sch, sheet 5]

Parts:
CN501, CN502, CN503, CN504, CN505, CN506, CN507, CN508: AVX_9155066; 9155006
IC501: PCA9534PW; TSSOP16
JP501, JP502, JP503, JP504: SINGULARITRON_CART_BASE

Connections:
+3V3: CN501.PAD2, CN504.PAD2, CN506.PAD2, CN508.PAD2; also elsewhere on the board
+5V: CN501.PAD1, CN504.PAD1, CN506.PAD1, CN508.PAD1; also elsewhere on the board
DETECT_MOD0: CN501.PAD4, IC501.5 (IO1)
DETECT_MOD1: CN504.PAD4, IC501.7 (IO3)
DETECT_MOD2: CN506.PAD4, IC501.10 (IO5)
DETECT_MOD3: CN508.PAD4, IC501.12 (IO7)
GND: CN501.PAD3, CN504.PAD3, CN506.PAD3, CN508.PAD3, IC501.1 (A0), IC501.2 (A1), IC501.3 (A2), IC501.8 (VSS); also elsewhere on the board
GPIO1_MOD0: CN501.PAD5; also elsewhere on the board
GPIO1_MOD1: CN504.PAD5; also elsewhere on the board
GPIO1_MOD2: CN506.PAD5; also elsewhere on the board
GPIO1_MOD3: CN508.PAD5; also elsewhere on the board
GPIO2_MOD0: CN501.PAD6; also elsewhere on the board
GPIO2_MOD1: CN504.PAD6; also elsewhere on the board
GPIO2_MOD2: CN506.PAD6; also elsewhere on the board
GPIO2_MOD3: CN508.PAD6; also elsewhere on the board
INT_HOTPLUG: IC501.13 (!INT); also elsewhere on the board
MISO: CN502.PAD3, CN503.PAD3, CN505.PAD3, CN507.PAD3; also elsewhere on the board
MOSI: CN502.PAD2, CN503.PAD2, CN505.PAD2, CN507.PAD2; also elsewhere on the board
SCK: CN502.PAD4, CN503.PAD4, CN505.PAD4, CN507.PAD4; also elsewhere on the board
SCL: IC501.14 (SCL); also elsewhere on the board
SCL1: CN502.PAD6, CN503.PAD6, CN505.PAD6, CN507.PAD6; also elsewhere on the board
SDA: IC501.15 (SDA); also elsewhere on the board
SDA1: CN502.PAD5, CN503.PAD5, CN505.PAD5, CN507.PAD5; also elsewhere on the board
SS_MOD0: CN502.PAD1, IC501.4 (IO0)
SS_MOD1: CN503.PAD1, IC501.6 (IO2)
SS_MOD2: CN505.PAD1, IC501.9 (IO4)
SS_MOD3: CN507.PAD1, IC501.11 (IO6)
VCC/2: IC501.16 (VDD); also elsewhere on the board

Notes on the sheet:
The DETECT pins need pullups to +3V goddammit

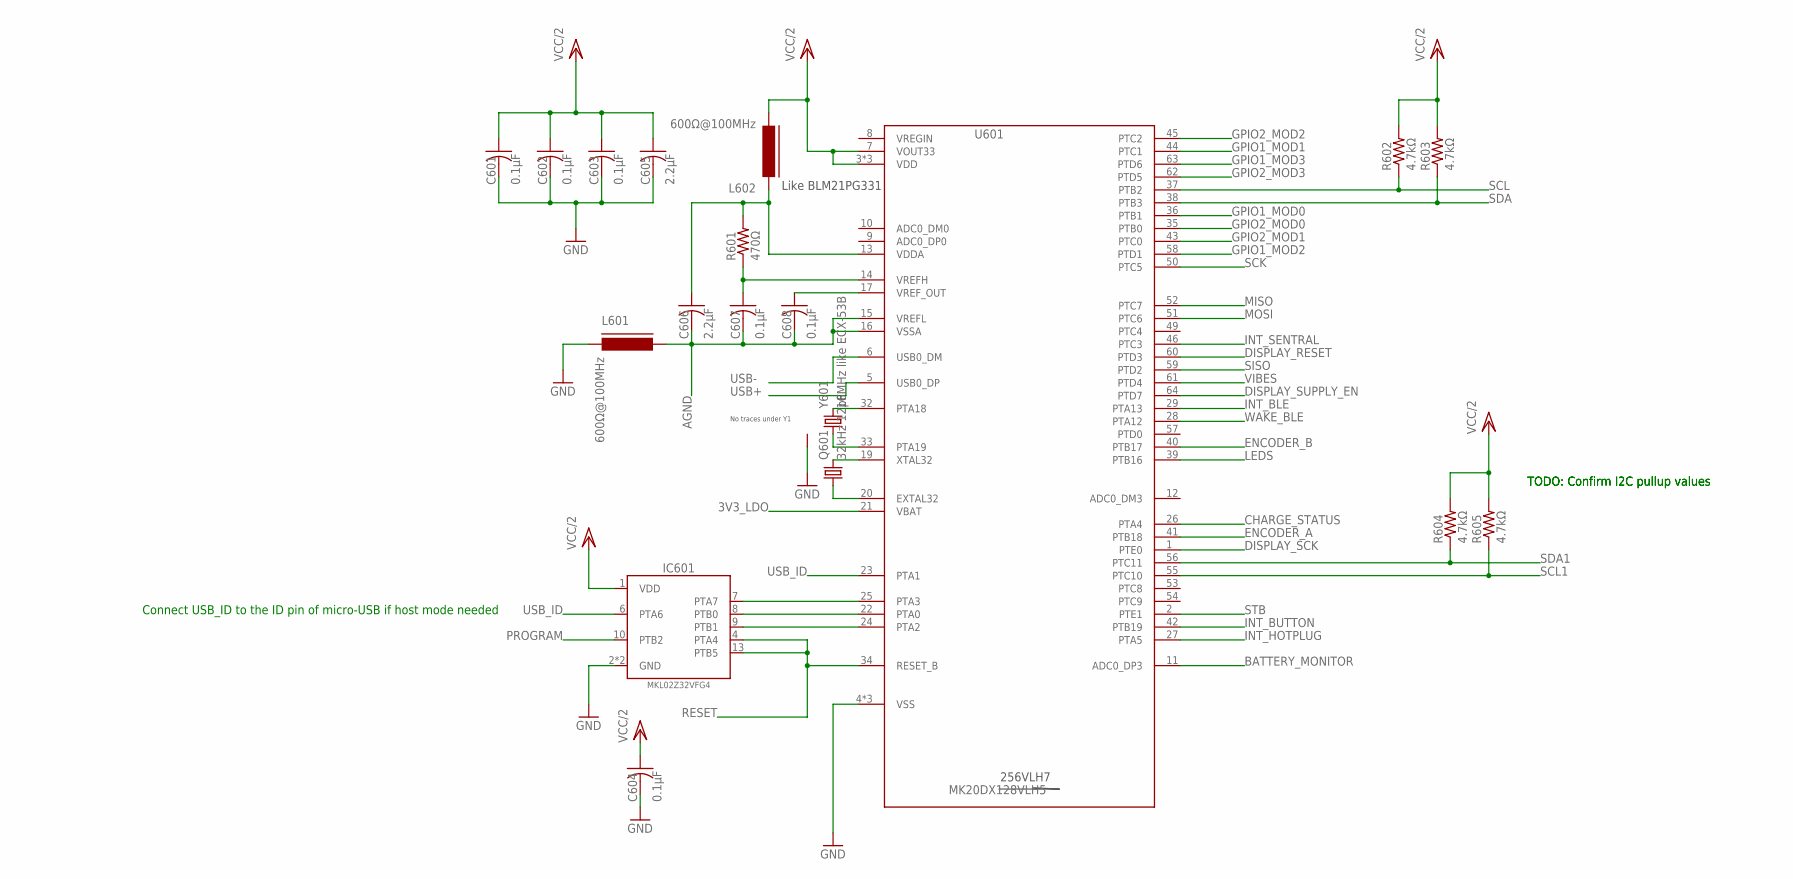
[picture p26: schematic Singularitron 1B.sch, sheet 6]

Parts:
C601, C602, C603, C604, C607, C608: 0.1µF; C0603
C605, C606: 2.2µF; C0603
IC601: MKL02Z32VFG4; QFN16-3X3
L601, L602: 600Ω@100MHz; FB603
Q601: 32kHz 12pF; FC-12M
R601: 470Ω; R0603
R602, R603, R604, R605: 4.7kΩ; R0603
U601: MK20DX128VLH5
Y601: 16MHz like ECX-53B; CRYSTAL-SMD-5X3

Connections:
3V3_LDO: U601.21 (VBAT); also elsewhere on the board
AGND: C606.2, C607.2, C608.2, L601.1, U601.15 (VREFL), U601.16 (VSSA)
BATTERY_MONITOR: U601.11 (ADC0_DP3); also elsewhere on the board
CHARGE_STATUS: U601.26 (PTA4); also elsewhere on the board
DISPLAY_RESET: U601.60 (PTD3); also elsewhere on the board
DISPLAY_SCK: U601.1 (PTE0); also elsewhere on the board
DISPLAY_SUPPLY_EN: U601.64 (PTD7); also elsewhere on the board
ENCODER_A: U601.41 (PTB18); also elsewhere on the board
ENCODER_B: U601.40 (PTB17); also elsewhere on the board
GND: C601.2, C602.2, C603.2, C604.2, C605.2, IC601.2 (GND), IC601.PAD (GND), L601.2, U601.4 (VSS), U601.31 (VSS), U601.47 (VSS), Y601.2 (SHIELD), Y601.4 (SHIELD); also elsewhere on the board
GPIO1_MOD0: U601.36 (PTB1); also elsewhere on the board
GPIO1_MOD1: U601.44 (PTC1); also elsewhere on the board
GPIO1_MOD2: U601.58 (PTD1); also elsewhere on the board
GPIO1_MOD3: U601.63 (PTD6); also elsewhere on the board
GPIO2_MOD0: U601.35 (PTB0); also elsewhere on the board
GPIO2_MOD1: U601.43 (PTC0); also elsewhere on the board
GPIO2_MOD2: U601.45 (PTC2); also elsewhere on the board
GPIO2_MOD3: U601.62 (PTD5); also elsewhere on the board
INT_BLE: U601.29 (PTA13); also elsewhere on the board
INT_BUTTON: U601.42 (PTB19); also elsewhere on the board
INT_HOTPLUG: U601.27 (PTA5); also elsewhere on the board
INT_SENTRAL: U601.46 (PTC3); also elsewhere on the board
LEDS: U601.39 (PTB16); also elsewhere on the board
MISO: U601.52 (PTC7); also elsewhere on the board
MOSI: U601.51 (PTC6); also elsewhere on the board
unnamed: IC601.7 (PTA7), U601.25 (PTA3)
unnamed: IC601.8 (PTB0), U601.22 (PTA0)
unnamed: IC601.9 (PTB1), U601.24 (PTA2)
unnamed: U601.32 (PTA18), Y601.3 (2)
unnamed: U601.33 (PTA19), Y601.1
unnamed: Q601.2, U601.19 (XTAL32)
unnamed: Q601.1, U601.20 (EXTAL32)
unnamed: C608.1, U601.17 (VREF_OUT)
unnamed: C607.1, R601.1, U601.14 (VREFH)
unnamed: C606.1, L602.1, R601.2, U601.13 (VDDA)
PROGRAM: IC601.10 (PTB2); also elsewhere on the board
RESET: IC601.4 (PTA4), IC601.13 (PTB5), U601.34 (RESET_B)
SCK: U601.50 (PTC5); also elsewhere on the board
SCL: R602.1, U601.37 (PTB2); also elsewhere on the board
SCL1: R605.1, U601.55 (PTC10); also elsewhere on the board
SDA: R603.1, U601.38 (PTB3); also elsewhere on the board
SDA1: R604.1, U601.56 (PTC11); also elsewhere on the board
SISO: U601.59 (PTD2); also elsewhere on the board
STB: U601.2 (PTE1); also elsewhere on the board
USB+: U601.5 (USB0_DP); also elsewhere on the board
USB-: U601.6 (USB0_DM); also elsewhere on the board
USB_ID: IC601.6 (PTA6), U601.23 (PTA1)
VCC/2: C601.1, C602.1, C603.1, C604.1, C605.1, IC601.1 (VDD), L602.2, R602.2, R603.2, R604.2, R605.2, U601.3 (VDD), U601.7 (VOUT33), U601.30 (VDD), U601.48 (VDD); also elsewhere on the board
VIBES: U601.61 (PTD4); also elsewhere on the board
WAKE_BLE: U601.28 (PTA12); also elsewhere on the board

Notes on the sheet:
256VLH7
Like BLM21PG331
No traces under Y1
Connect USB_ID to the ID pin of micro-USB if host mode needed
TODO: Confirm I2C pullup values

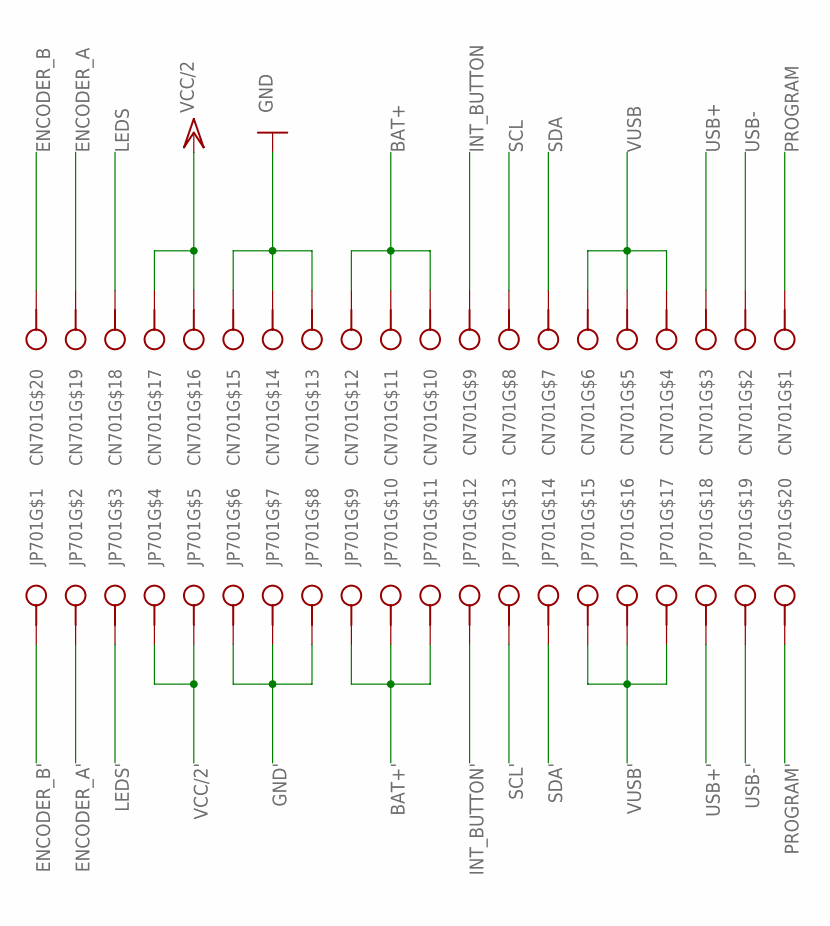
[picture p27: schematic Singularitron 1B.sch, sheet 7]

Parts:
CN701: HFW20R-1ST; HFW20R-1STE1LF
JP701: FFC_1MM_20POS_DIRECT

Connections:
BAT+: CN701.P$10, CN701.P$11, CN701.P$12; also elsewhere on the board
BAT+': JP701.P$9, JP701.P$10, JP701.P$11; also elsewhere on the board
ENCODER_A: CN701.P$19; also elsewhere on the board
ENCODER_A': JP701.P$2; also elsewhere on the board
ENCODER_B: CN701.P$20; also elsewhere on the board
ENCODER_B': JP701.P$1; also elsewhere on the board
GND: CN701.P$13, CN701.P$14, CN701.P$15; also elsewhere on the board
GND': JP701.P$6, JP701.P$7, JP701.P$8; also elsewhere on the board
INT_BUTTON: CN701.P$9; also elsewhere on the board
INT_BUTTON': JP701.P$12; also elsewhere on the board
LEDS: CN701.P$18; also elsewhere on the board
LEDS': JP701.P$3; also elsewhere on the board
PROGRAM: CN701.P$1; also elsewhere on the board
PROGRAM': JP701.P$20; also elsewhere on the board
SCL: CN701.P$8; also elsewhere on the board
SCL': JP701.P$13; also elsewhere on the board
SDA: CN701.P$7; also elsewhere on the board
SDA': JP701.P$14; also elsewhere on the board
USB+: CN701.P$3; also elsewhere on the board
USB+': JP701.P$18; also elsewhere on the board
USB-: CN701.P$2; also elsewhere on the board
USB-': JP701.P$19; also elsewhere on the board
VCC/2: CN701.P$16, CN701.P$17; also elsewhere on the board
VCC/2': JP701.P$4, JP701.P$5; also elsewhere on the board
VUSB: CN701.P$4, CN701.P$5, CN701.P$6; also elsewhere on the board
VUSB': JP701.P$15, JP701.P$16, JP701.P$17; also elsewhere on the board

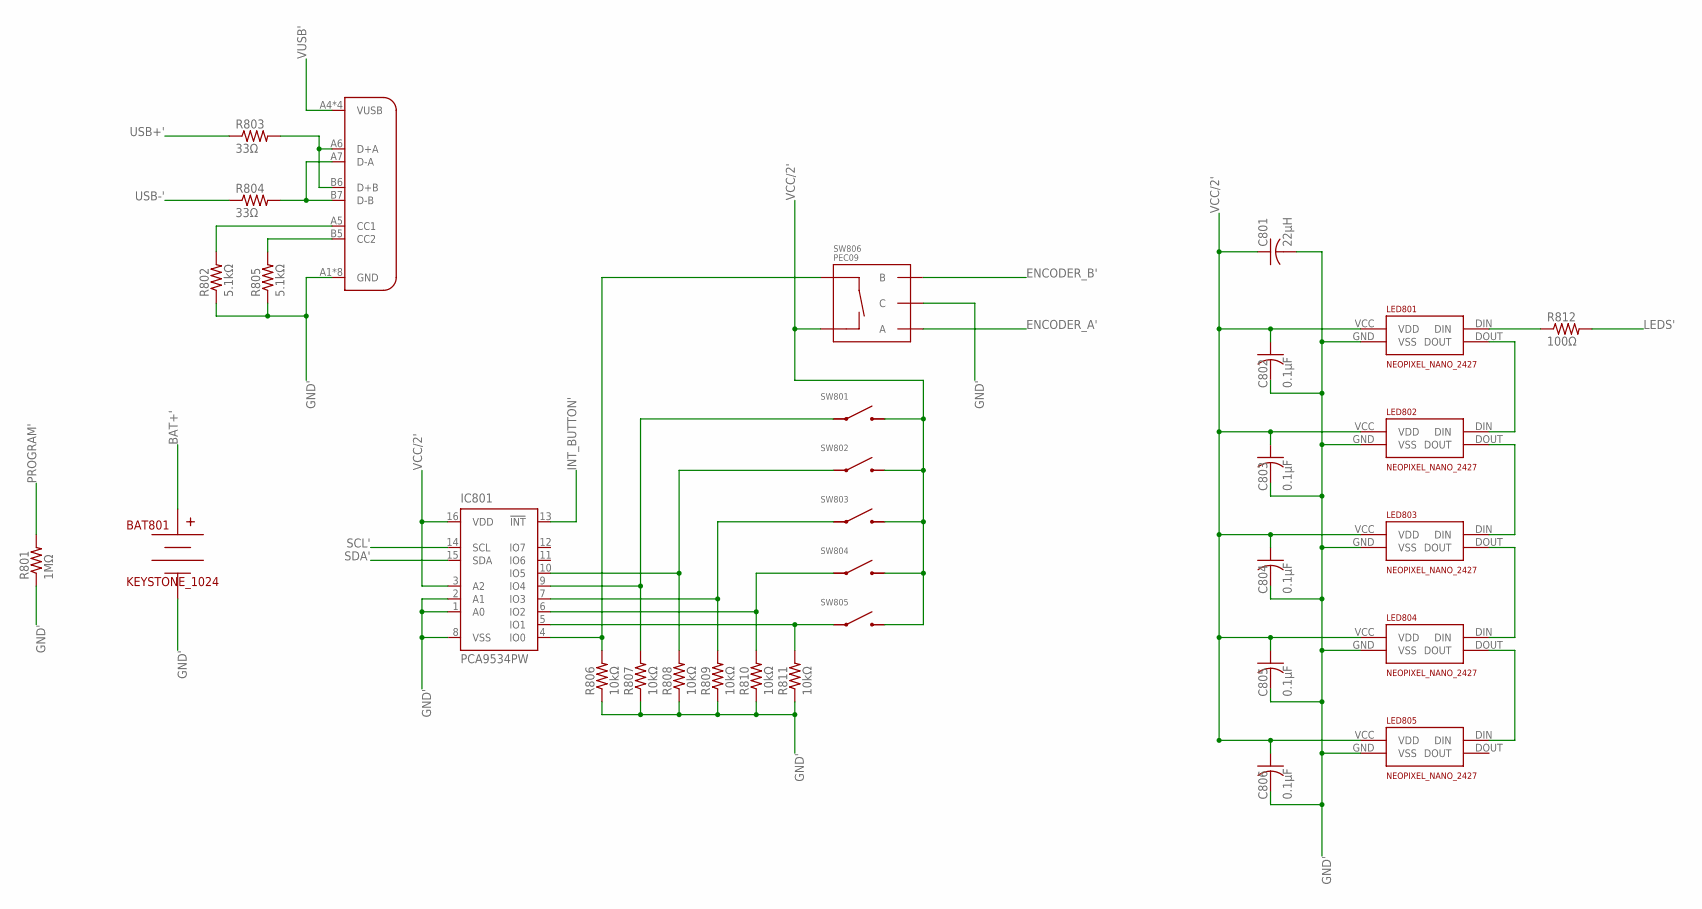
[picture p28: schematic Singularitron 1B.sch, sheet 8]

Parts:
BAT801: KEYSTONE_1024; KEYSTONE-1024-PROVISIONAL
C801: 22µH; C1210
C802, C803, C804, C805, C806: 0.1µF; C0603
CN801: 12401548E4#2A
IC801: PCA9534PW; TSSOP16
LED801, LED802, LED803, LED804, LED805: NEOPIXEL_NANO_2427; SK6805-2427
R801: 1MΩ; R0603
R802, R805: 5.1kΩ; R0603
R803, R804: 33Ω; R0603
R806, R807, R808, R809, R810, R811: 10kΩ; R0603
R812: 100Ω; R0603
SW801, SW802, SW803, SW804, SW805: TACTILE_SWITCHTL3301-G; TL3301-X-FXXX-X-G
SW806: PEC09; PEC09-2X20X-TXXXX

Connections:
BAT+': BAT801.+ (V+); also elsewhere on the board
ENCODER_A': SW806.A; also elsewhere on the board
ENCODER_B': SW806.B; also elsewhere on the board
GND': BAT801.- (V-), C801.2, C802.2, C803.2, C804.2, C805.2, C806.2, CN801.A1 (GND), CN801.A12 (GND), CN801.B1 (GND), CN801.B12 (GND), CN801.SHIELD1 (GND), CN801.SHIELD2 (GND), CN801.SHIELD3 (GND), CN801.SHIELD4 (GND), IC801.1 (A0), IC801.2 (A1), IC801.8 (VSS), LED801.GND (VSS), LED802.GND (VSS), LED803.GND (VSS), LED804.GND (VSS), LED805.GND (VSS), R801.1, R802.1, R805.1, R806.1, R807.1, R808.1, R809.1, R810.1, R811.1, SW806.C; also elsewhere on the board
INT_BUTTON': IC801.13 (!INT); also elsewhere on the board
LEDS': R812.2; also elsewhere on the board
unnamed: CN801.A6 (D+A), CN801.B6 (D+B), R803.2
unnamed: IC801.5 (IO1), R811.2, SW805.P$1, SW805.P$2
unnamed: IC801.6 (IO2), R810.2, SW804.P$1, SW804.P$2
unnamed: IC801.7 (IO3), R809.2, SW803.P$1, SW803.P$2
unnamed: CN801.A7 (D-A), CN801.B7 (D-B), R804.2
unnamed: IC801.10 (IO5), R808.2, SW802.P$1, SW802.P$2
unnamed: IC801.9 (IO4), R807.2, SW801.P$1, SW801.P$2
unnamed: LED801.DOUT, LED802.DIN
unnamed: LED802.DOUT, LED803.DIN
unnamed: LED803.DOUT, LED804.DIN
unnamed: LED804.DOUT, LED805.DIN
unnamed: LED801.DIN, R812.1
unnamed: IC801.4 (IO0), R806.2, SW806.D (SW+)
unnamed: CN801.A5 (CC1), R802.2
unnamed: CN801.B5 (CC2), R805.2
PROGRAM': R801.2; also elsewhere on the board
SCL': IC801.14 (SCL); also elsewhere on the board
SDA': IC801.15 (SDA); also elsewhere on the board
USB+': R803.1; also elsewhere on the board
USB-': R804.1; also elsewhere on the board
VCC/2': C801.1, C802.1, C803.1, C804.1, C805.1, C806.1, IC801.3 (A2), IC801.16 (VDD), LED801.VCC (VDD), LED802.VCC (VDD), LED803.VCC (VDD), LED804.VCC (VDD), LED805.VCC (VDD), SW801.P$3, SW801.P$4, SW802.P$3, SW802.P$4, SW803.P$3, SW803.P$4, SW804.P$3, SW804.P$4, SW805.P$3, SW805.P$4, SW806.E (SW-); also elsewhere on the board
VUSB': CN801.A4 (VUSB), CN801.A9 (VUSB), CN801.B4 (VUSB), CN801.B9 (VUSB); also elsewhere on the board

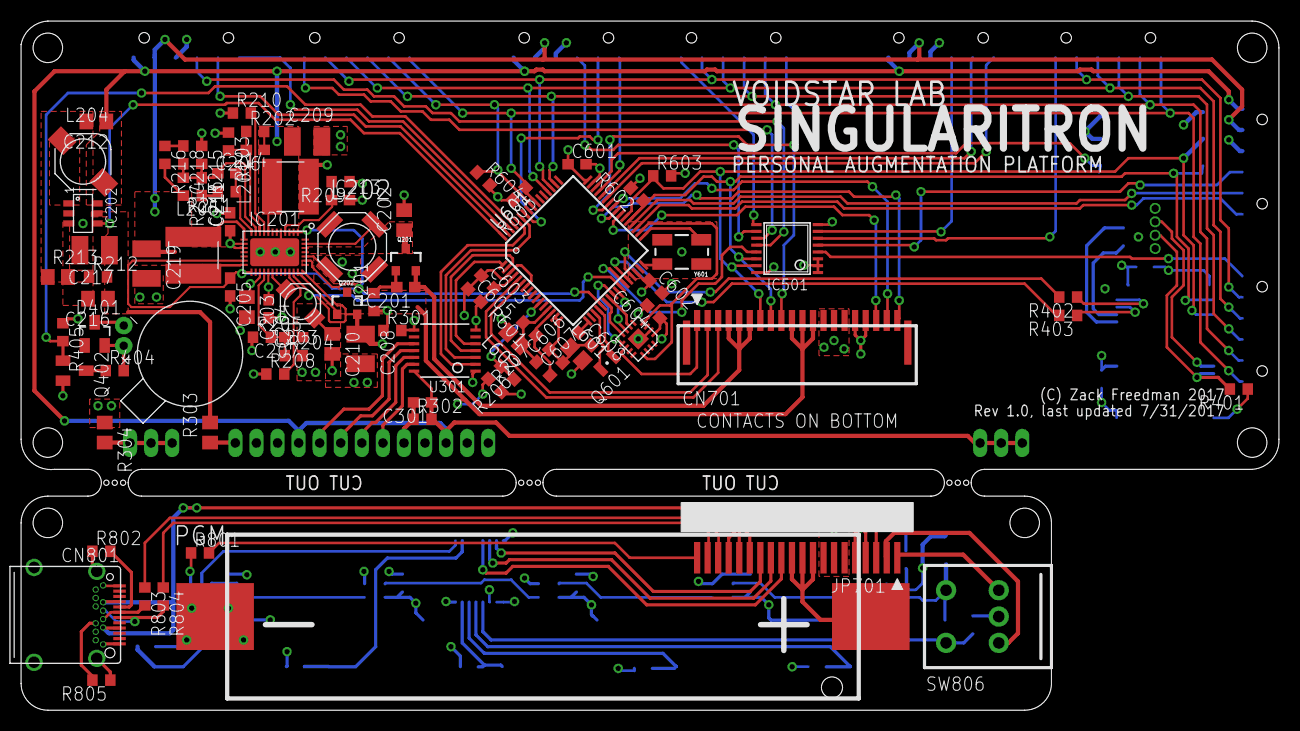
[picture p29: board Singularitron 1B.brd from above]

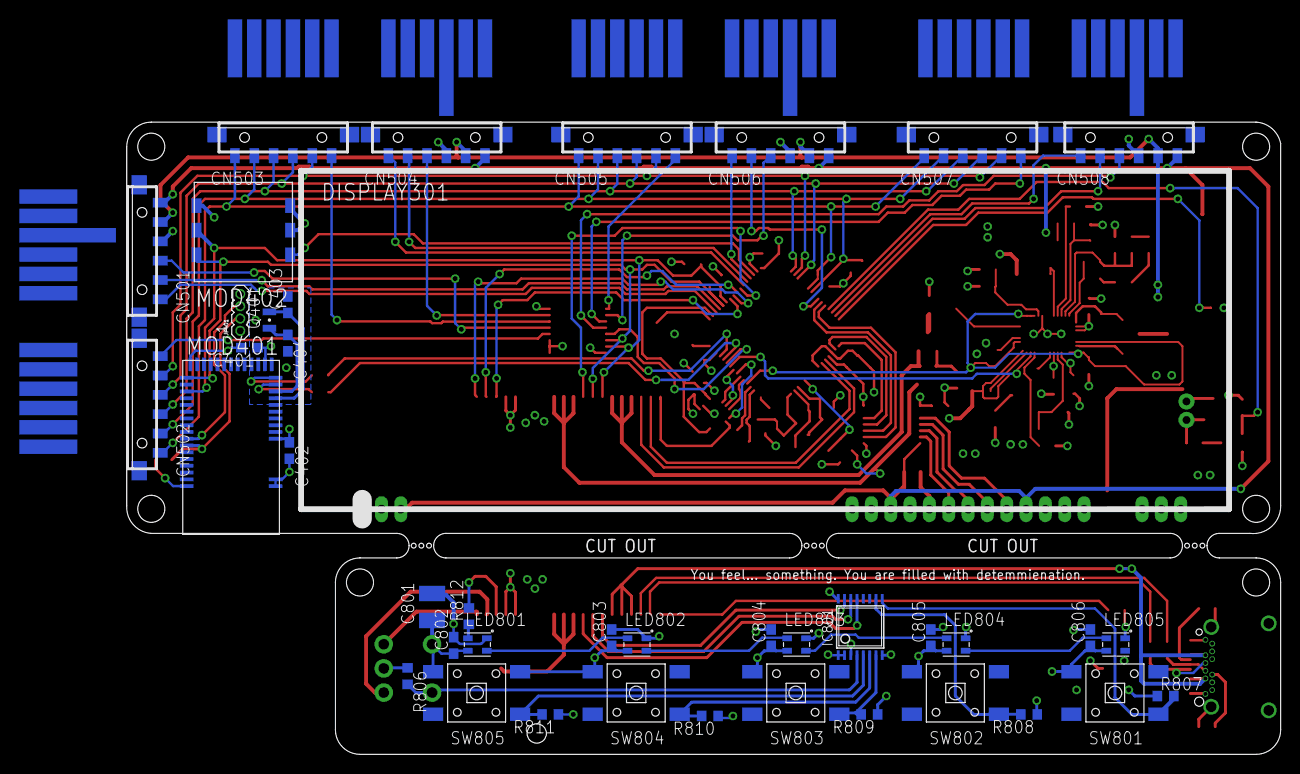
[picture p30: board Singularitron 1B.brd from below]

Board: 4 copper layers, 119.4 x 65.4 mm, 133 parts (41 on the bottom side), 126 nets.

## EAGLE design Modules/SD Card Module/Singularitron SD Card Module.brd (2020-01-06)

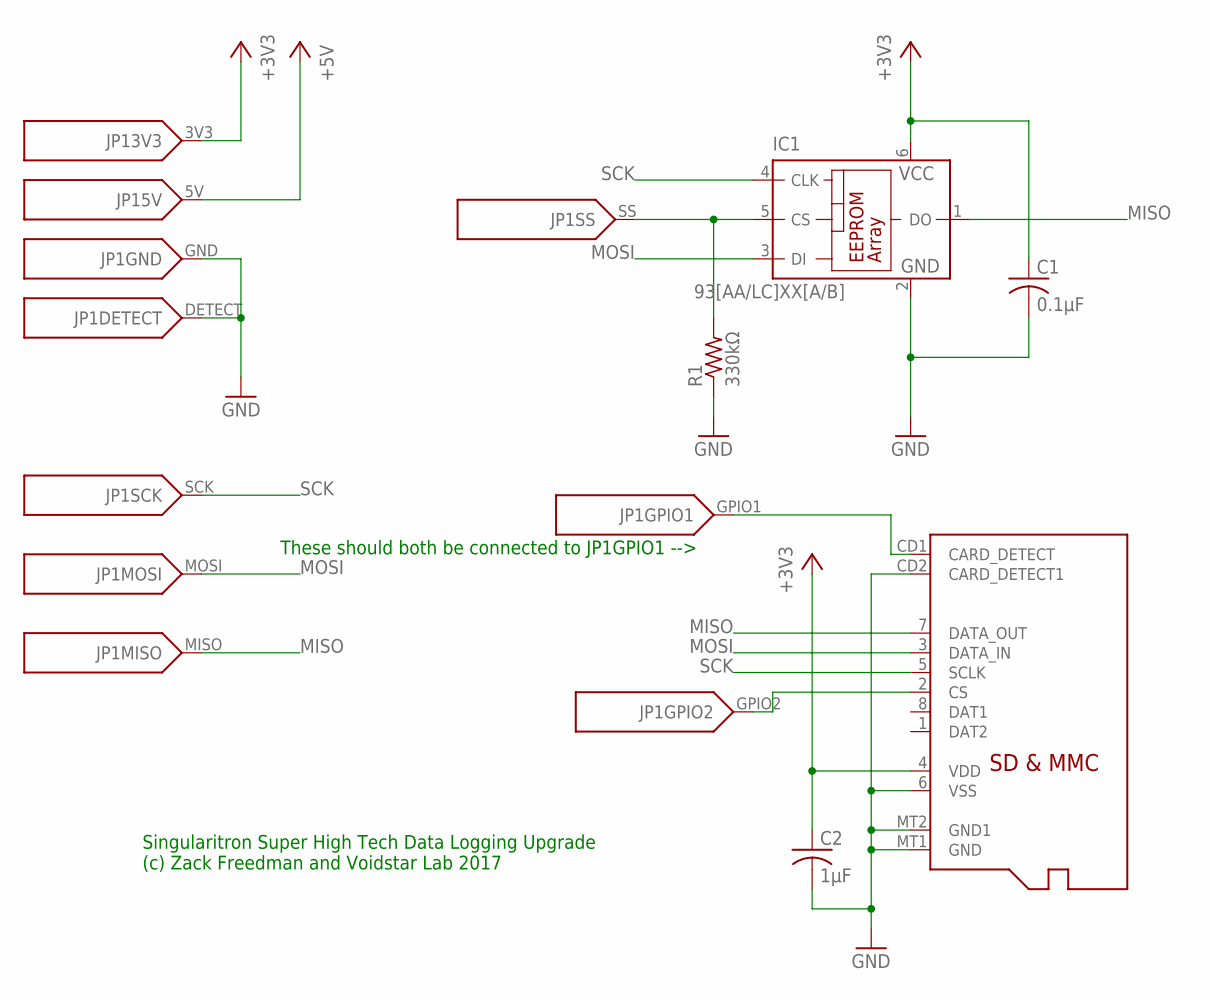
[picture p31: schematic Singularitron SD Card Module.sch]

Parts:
C1: 0.1µF; C0603
C2: 1µF; C0603
IC1: 93[AA/LC]XX[A/B]; SOT23-6
JP1: SINGULARITRON_CART_BASE
JP2: MICROSD
R1: 330kΩ; R0603

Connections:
+3V3: C1.1, C2.1, IC1.6 (VCC), JP1.3V3, JP2.4 (VDD)
+5V: JP1.5V
GND: C1.2, C2.2, IC1.2 (GND), JP1.DETECT, JP1.GND, JP2.6 (VSS), JP2.CD2 (CARD_DETECT1), JP2.MT1 (GND), JP2.MT2 (GND1), R1.1
MISO: IC1.1 (DO), JP1.MISO, JP2.7 (DATA_OUT)
MOSI: IC1.3 (DI), JP1.MOSI, JP2.3 (DATA_IN)
unnamed: IC1.5 (CS), JP1.SS, R1.2
unnamed: JP1.GPIO1, JP2.CD1 (CARD_DETECT)
unnamed: JP1.GPIO2, JP2.2 (CS)
SCK: IC1.4 (CLK), JP1.SCK, JP2.5 (SCLK)

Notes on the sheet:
Singularitron Super High Tech Data Logging Upgrade (c) Zack Freedman and Voidstar Lab 2017
These should both be connected to JP1GPIO1 -->

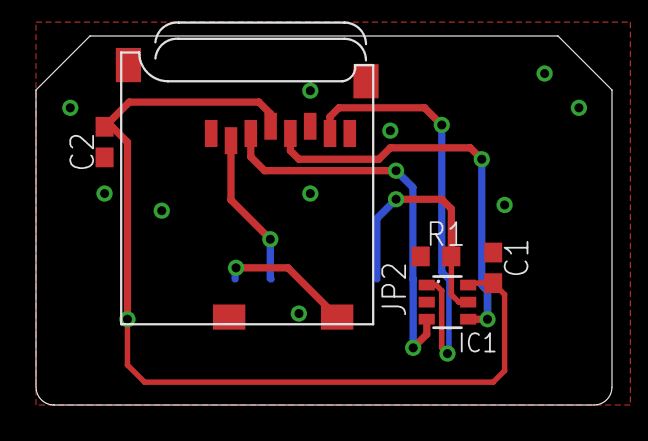
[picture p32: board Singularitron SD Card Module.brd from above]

Board: 2 copper layers, 32.0 x 20.5 mm, 6 parts (0 on the bottom side), 8 nets.

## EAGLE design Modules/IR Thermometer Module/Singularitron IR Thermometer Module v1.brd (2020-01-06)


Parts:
C1, C2: 0.1µF; C0603
IC1: 93[AA/LC]XX[A/B]; SOT23-6
JP1: SINGULARITRON_CART_BASE
LASER-ANODE: 1,6/0,9
LASER-CATHODE: 1,6/0,9
Q1: MOSFET-NREFLOW; SOT23
R1: 330kΩ; R0603
R2: 10kΩ; R0603
U1: MLX90614_; TO-39

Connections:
+3V3: C1.1, C2.1, IC1.6 (VCC), JP1.3V3, U1.3 (VDD)
+5V: JP1.5V, LASER-ANODE.1
GND: C1.2, C2.2, IC1.2 (GND), JP1.DETECT, JP1.GND, Q1.2 (S), R1.1, R2.1, U1.4 (VSS)
LASER: JP1.GPIO2, Q1.1 (G), R2.2
unnamed: IC1.5 (CS), JP1.SS, R1.2
unnamed: JP1.SCL, U1.1 (SCL/VZ)
unnamed: JP1.SDA, U1.2 (PWM/SDA)
unnamed: LASER-CATHODE.1, Q1.3 (D)
unnamed: IC1.4 (CLK), JP1.SCK
unnamed: IC1.3 (DI), JP1.MOSI
unnamed: IC1.1 (DO), JP1.MISO

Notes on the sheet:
Singularitron Module Name (c) Zack Freedman and Voidstar Lab 2017
Chinesium 5mW 5V laser diode


Board: 4 copper layers, 32.0 x 18.0 mm, 10 parts (0 on the bottom side), 11 nets.

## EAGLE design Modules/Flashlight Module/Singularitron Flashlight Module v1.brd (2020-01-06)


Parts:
C1: 0.1µF; C0603
C2: 10µF 6.3V X5R; C0805
C3, C4: 1µF 10V X7R; C0805
C5: 0.01µF 16V X7R; C0603
D1: MBRX120LF-TP; SOD-123
D3: CMDSH-3; SOD-323F
HW_LED1: CARCLO_10771_10772; CARCLO_10MM_NARROW_MEDIUM
IC1: 93[AA/LC]XX[A/B]; SOT23-6
IC2: LM3405; SOT-23
JP1: SINGULARITRON_CART_BASE
L1: TYS40304R7M-10
R1: 330kΩ; R0603
R2: 300mΩ; R0805
U$1: LUXEON-REBEL

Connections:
+3V3: C1.1, IC1.6 (VCC), JP1.3V3
+5V: C2.1, D3.A, IC2.P5 (VIN), JP1.5V
GND: C1.2, C2.2, C3.2, D1.A, IC1.2 (GND), IC2.P2 (GND), JP1.DETECT, JP1.GND, R1.1, R2.1, U$1.P$3 (S)
unnamed: IC1.5 (CS), JP1.SS, R1.2
unnamed: IC1.4 (CLK), JP1.SCK
unnamed: IC1.3 (DI), JP1.MOSI
unnamed: IC1.1 (DO), JP1.MISO
unnamed: IC2.P4 (EN/DIM), JP1.GPIO1
unnamed: C5.1, D3.C, IC2.P1 (BOOST)
unnamed: C5.2, D1.C, IC2.P6 (SW), L1.P$2 (2)
unnamed: C3.1, C4.1, L1.P$1 (1), U$1.ANODE (A)
unnamed: C4.2, IC2.P3 (FB), R2.2, U$1.CATHODE (C)

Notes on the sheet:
Singularitron Flashlight Module (c) 2017 Zack Freedman and Voidstar Lab


Board: 2 copper layers, 32.0 x 18.0 mm, 15 parts (0 on the bottom side), 12 nets.

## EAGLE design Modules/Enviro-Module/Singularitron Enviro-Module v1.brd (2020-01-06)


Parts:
C1, C3, C4, C5: 0.1µF; C0603
C2: 1µF; C0603
IC1: 93[AA/LC]XX[A/B]; SOT23-6
JP1: SINGULARITRON_CART_BASE
R1: 330kΩ; R0603
R2: 4.7kΩ; R0603
R3: 100kΩ; R0603
U1: CCS811; LGA10
U2: BME280; BME280_LGA
U3: ZOPT220X; LGA6

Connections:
+3V3: C1.1, C2.1, C3.1, C4.1, C5.1, IC1.6 (VCC), JP1.3V3, R2.2, U1.6 (VDD), U2.P$2 (!CS), U2.P$5 (SDO/ADR), U2.P$6 (VDDIO), U2.P$8 (VDD), U3.3 (VDD)
+5V: JP1.5V
GND: C1.2, C2.2, C3.2, C4.2, C5.2, IC1.2 (GND), JP1.DETECT, JP1.GND, R1.1, R3.1, U1.1 (ADDR), U1.EP (GND), U2.P$1 (GND1), U2.P$7 (GND2), U3.5 (GND)
unnamed: IC1.5 (CS), JP1.SS, R1.2
unnamed: IC1.4 (CLK), JP1.SCK
unnamed: IC1.3 (DI), JP1.MOSI
unnamed: IC1.1 (DO), JP1.MISO
unnamed: R2.1, U1.2 (!RESET!)
unnamed: JP1.GPIO2, R3.2, U1.7 (!WAKE!)
unnamed: JP1.GPIO1, U1.3 (!INT!)
unnamed: U1.4 (PWM), U1.5 (SENSE)
SCL: JP1.SCL, U1.10 (SCL), U2.P$4 (SCK/SCL), U3.1 (SCL)
SDA: JP1.SDA, U1.9 (SDA), U2.P$3 (SDI/SDA), U3.2 (SDA)

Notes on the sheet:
Singularitron Enviro-Module (c) Zack Freedman and Voidstar Lab 2017


Board: 2 copper layers, 32.0 x 18.0 mm, 13 parts (0 on the bottom side), 12 nets.

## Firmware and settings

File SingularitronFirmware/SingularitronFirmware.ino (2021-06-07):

#include <i2c_t3.h>
#include <Encoder.h>
#include <TimeLib.h>
#include <SPI.h>
#include <LowPower_Teensy3.h>
//#include <Snooze.h>

/* The most complicated useless side project of all time.
   Copyright 2017 Zack Freedman
*/

// The following dumb bullshit just lets us turn off serial debug

#define DEBUG

#define GET_MACRO(_1, _2, NAME, ...) NAME
#ifdef DEBUG
#define debug_print_formatted(x, y) Serial.print(x,y)
#define debug_print_noformat(x) Serial.print(x)
#define debug_println_formatted(x, y) Serial.println(x, y)
#define debug_println_noformat(x) Serial.println(x)
#define debug_write(x) Serial.write(x)
#else
#define debug_print_formatted(x, y)
#define debug_print_noformat(x)
#define debug_println_formatted(x, y)
#define debug_println_noformat(x)
#define debug_write(x)
#endif
#define debug_print(...) GET_MACRO(__VA_ARGS__, debug_print_formatted, debug_print_noformat)(__VA_ARGS__)
#define debug_println(...) GET_MACRO(__VA_ARGS__, debug_println_formatted, debug_println_noformat)(__VA_ARGS__)

#define sanity(x) debug_println("Sanity " #x);

// End dumb debugging bullshit

#include "pins.h"
#include "states.h"
#include "flavortext.h"

#include "settings.h"

#include "imu.h"
#include "bufferedVfd.h"
#include "bufferedLeds.h"
#include "cartEeprom.h"

#include "app.h"
#include "cart.h"
#include "systemApps.h"

#include "breathalyzer.h"
#include "enviromodule.h"
#include "fluxgate.h"
#include "frickinlaser.h"
#include "gratuitousflashlight.h"
#include "lightSensor.h"
#include "oledCart.h"
#include "pulseOxCart.h"
#include "sdcardmodule.h"
#include "testModule.h"
#include "thermodule.h"

#define noAnimation 0
#define rightWipe 1
#define leftWipe 2

float headingOffset = -45.0;

IMU imu = IMU();
// This is the entire compass legend. A subset of it is rendered as the compass dial.
// 0xA5 is a dot
char compassLegend[] = {'W', 0xA5, 0xA5, 0xA5, 0xA5, 'N', 0xA5, 0xA5, 0xA5, 0xA5, 'E', 0xA5, 0xA5, 0xA5, 0xA5, 'S', 0xA5, 0xA5, 0xA5, 0xA5};
#define compassLegendSize 20

Encoder knob(encoderB, encoderA);
long oldPosition = 0;

// SnoozeDigital didn't work so good. Maybe try again some time, sleep is pretty jank
//SnoozeDigital snoozeDigital;
//SnoozeTimer snoozeTimer;
//SnoozeUSBSerial snoozeUsb;
//SnoozeSPI snoozeSpi;
//SnoozeBlock snoozeConfigWithBackgroundUpdates(snoozeDigital, snoozeTimer, snoozeUsb);//, snoozeSpi);
//SnoozeBlock snoozeConfigNoBackgroundUpdates(snoozeDigital, snoozeUsb);//, snoozeSpi);
bool justWokeUp;
IntervalTimer sleepingBackgroundUpdateTimer;

#define homeButtonColor 0x38FF38
//#define homeButtonColor CRGB::DarkCyan

char widgetBuffer[10];
BufferedVfd display;
BufferedLeds leds;
CRGB preAnimationLeds[5];
byte activeAnimation = noAnimation;
char preAnimationFramebuffer[4][20];
char flavorTextBuffer[4][21];
elapsedMillis timeSinceAnimationStarted;

#define maxChargeReading 3700 // 12-bit ADC reading of 4.15V divided down to 3.07V-ish
#define minChargeReading 3200 // 12-bit ADC reading of 3.4V divided down to 2.58V-ish
#define chargeReadingRange maxChargeReading - minChargeReading
#define ntcFaultDutyCycleLow 6.25f // %
#define ntcFaultDutyCycleHigh 93.75f // %
#define badBatteryDutyCycleLow 12.5f // %
#define badBatteryDutyCycleHigh 87.5f // %
#define dutyCycleJitter 2.0f // Percentage points
#define chargePinPeriod 28 // 35KHz frequency = 28.57us period
#define chargePinPeriodJitter 2 // us
#define batteryNotCharging 0
#define batteryCharging 1
#define batteryNtcFault 2
#define batteryChargeFault 3
volatile bool chargePinState;
volatile unsigned long chargePinChangeTimestamp;
volatile unsigned long chargePinHighTime;
volatile unsigned long chargePinLowTime;
byte batteryState = batteryNotCharging;
int batteryBars = 10; // Used to stabilize charge indicator
char batteryIconChar = 0xFF; // Used to draw battery icon near charge indicator

bool phoneConnected = false;
char phoneIconChar = 0xFF;

byte firstWidgetToRender = 0; // Used to scroll widgets. This widget's line and the following line of widgets are displayed on the homescreen.

byte state = indeterminateState;
byte previousState = indeterminateState;
byte activeCartSlot = 0xFF;
byte previousCartSlot = 0xFF;

bool homeQuickfire = false; // Used for quick time-checking mode
elapsedMillis timeSinceInterstitial; // Used to display insertion/ejection feedback

TEENSY3_LP power = TEENSY3_LP();
elapsedMillis timeAwake;

volatile bool mustPollButtons, mustPollCarts, mustPollImu;

const byte buttonMasks[4] = {button0Mask, button1Mask, button2Mask, button3Mask}; // Used to create and read bitmasks in App.OnControlEvent()
byte lastButtonStates = 0x00; // Bitmask of previous button states for edge detection, little-endian
unsigned long knobDownTimestamp, homeDownTimestamp;
unsigned long buttonDownTimestamps[4];  // Used to calculate hold
bool knobJustClicked, homeJustClicked;
bool buttonsJustClicked[4];
bool knobIsHeld, homeIsHeld;
bool buttonsHeld[4];
bool homeHoldHandled;

#define cartDetectSettleTime 50 // ms that cart detect pin must remain in same state before it's considered to be inserted or ejected
unsigned long cartDetectTimestamps[4];
Cartridge * carts[4];
App * activeApp;
byte lastCartStates = 0b10101010; // Bitmask of previous carts for edge detection, little-endian. Active low, so this represents "everything ejected".

#define STARTWOKE

void setup() {
  Serial.begin(9600);
  ble.begin(9600);

  loadSettings();

  analogReadResolution(12);
  //  analogReference(INTERNAL);

  // Buzz buzz
  pinMode(vibes, OUTPUT);

  // Configure interrupts
  pinMode(buttonInterruptPin, INPUT_PULLUP);
  pinMode(hotplugInterruptPin, INPUT_PULLUP);
  pinMode(sentralInterruptPin, INPUT); // Shouldn't need a pullup
  pinMode(chargeStatusPin, INPUT_PULLUP);

  //  snoozeDigital.pinMode(buttonInterruptPin, INPUT_PULLUP, FALLING);
  //  snoozeDigital.pinMode(hotplugInterruptPin, INPUT_PULLUP, FALLING);
  //  snoozeDigital.pinMode(chargeStatusPin, INPUT_PULLUP, FALLING);

  // Configure interfaces
  SPI.begin();
  Wire.begin(I2C_MASTER, 0x00, I2C_PINS_18_19, I2C_PULLUP_EXT, I2C_RATE_400);
  Wire.setDefaultTimeout(2000);
  Wire1.begin(I2C_MASTER, 0x00, I2C_PINS_29_30, I2C_PULLUP_EXT, I2C_RATE_400);
  Wire1.setDefaultTimeout(2000);

  setSyncProvider(getTeensy3Time); // Draw current time from internal RTC
  setSyncInterval(60); // Read internal RTC every 60 seconds. Necessary? Correct interval? Hrmmm?

  randomSeed(now());

  // Initialize IMU
  imu.setup();
  //  attachInterrupt(digitalPinToInterrupt(sentralInterruptPin), onImuEvent, RISING);

  // Initialize display
  display.setup();
  display.setBrightness(displayBrightness);
  leds.setup();
  leds.setBrightness(ledBrightness);

  // Start with display off in case device is recharging empty battery
#ifdef STARTWOKE
  display.powerUp();
#endif

  // Initialize button driver
  for (int i = 0; i < 3; i++) {
    Wire.beginTransmission(buttonDriver);
    Wire.write(0x03); // Select control register
    Wire.write(0x3F); // Assign pins 0-5 to inputs
    byte error = Wire.endTransmission();
    if (error == 0) {
      debug_println("Button driver online");
      break;
    }
    else {
      debug_print("Button driver got error ");
      debug_println(error);
      delay(100);
    }
  }

  // Initialize cartridge IO expander
  for (int i = 0; i < 3; i++) {
    Wire.beginTransmission(cartIOExpander);
    Wire.write(0x03); // control register
    Wire.write(0b10101010); // SS pins are outputs, Detect pins are inputs
    byte error = Wire.endTransmission();
    if (error == 0) {
      debug_println("Cart IO expander online");
      break;
    }
    else {
      debug_print("Cart driver got error ");
      debug_println(error);
      delay(100);
    }
  }

  restoreInterrupts();
  pollButtons();
  pollCarts();

  // Initialize battery shit
  chargePinState = digitalRead(chargeStatusPin);
  attachInterrupt(digitalPinToInterrupt(chargeStatusPin), onBatteryEvent, CHANGE);

  #ifdef STARTWOKE
    switchStateTo(homeScreen);
  #endif
  #ifndef STARTWOKE
    switchStateTo(sleeping);
  #endif

//  switchStateTo(systemApp, byte(1));

//  delay(1000);
//  byte target = 0;
//  int valueToWrite = fluxgateModuleId;
//  debug_print("Programming cart on slot "); debug_println(target);
////  openEeprom(target);
//  debug_print("Value at 0 is 0x"); debug_println(readEeprom(0x00), HEX);
//  writeEeprom(0, valueToWrite, target);
//  debug_print("Wrote ID 0x"); debug_println(valueToWrite, HEX);
//  debug_print("Value at 0 is now 0x"); debug_println(readEeprom(0x00), HEX);
//  closeEeprom();
  //      delay(10000);
}

void loop() {
  // Save power if we're sleeping
  if (state == sleeping &&
      activeAnimation == noAnimation &&
      lastButtonStates == 0b11000000 &&
      cartDetectTimestamps[0] == 0 &&
      cartDetectTimestamps[1] == 0 &&
      cartDetectTimestamps[2] == 0 &&
      cartDetectTimestamps[3] == 0) { // Buttons/carts prevent sleep so time-related changes can be detected

    debug_println("Entering power save");
    display.powerDown();
    //    imu.sleep(); // DO NOT touch mustPollImu - don't want to clear it while the Status register is full
    ble.end();

    unsigned long nextBackgroundUpdate = 0;
    for (byte i = 0; i < 4; i++)
      if (carts[i] != NULL && carts[i]->backgroundUpdateInterval > 0
          && (carts[i]->backgroundUpdateInterval - carts[i]->lastBackgroundUpdateTimestamp) > nextBackgroundUpdate)
        nextBackgroundUpdate = carts[i]->backgroundUpdateInterval - carts[i]->lastBackgroundUpdateTimestamp;
    if (nextBackgroundUpdate > 0) {
      Serial.println(nextBackgroundUpdate);
      //      snoozeTimer.setTimer(nextBackgroundUpdate);
      //      Snooze.sleep(snoozeConfigWithBackgroundUpdates);
      sleepingBackgroundUpdateTimer.begin(wakeToUpdate, nextBackgroundUpdate * 1000); // This function uses microseconds
    }
    //    else Snooze.sleep(snoozeConfigNoBackgroundUpdates);

    //    delay(1000);
    power.Sleep();

    sleepingBackgroundUpdateTimer.end();

    /* ...dreams of enslaving feeble meatsacks... */

    debug_println("Leaving power save");
    ble.begin(9600);
    justWokeUp = mustPollButtons = mustPollCarts = true; // Might not need this
    setSyncProvider(getTeensy3Time); // Need to resync after waking up
    setSyncInterval(60); // Might not be necessary to do this here
  }

  while (ble.available()) {
    char incoming = ble.read();
    debug_print("BLE: ");
    debug_println(incoming);
    if (incoming == 'C') phoneConnected = true;
    else if (incoming == 'D') phoneConnected = false;
  }

  unsigned long startTime = micros();

  // Gentlemen, start your buffers

  // Poll shit
  if (mustPollButtons) pollButtons(); // Seems kinda obvious
  if (mustPollCarts) pollCarts(); // Yup
  //  if (mustPollImu) {
  if (digitalRead(sentralInterruptPin)) {
    imu.poll();
    //    mustPollImu = false;
  }

  // Handle recently inserted/ejected carts
  for (byte slot = 0; slot < 4; slot++) {
    if (cartDetectTimestamps[slot] > 0 && (millis() - cartDetectTimestamps[slot] >= cartDetectSettleTime)) {
      cartDetectTimestamps[slot] = 0;

      if (state == sleeping) switchStateTo(homeScreen); // Changing carts wakes from sleep
      else timeAwake = 0; // Changing carts resets sleep timeout

      if ((lastCartStates & (0b10 << (slot * 2))) == 0) { // True if cart insertion caused the last change
        if (carts[slot] == NULL) {
          debug_print("OK, cart "); debug_print(slot); debug_println(" is really inserted");

          // Read cart's ID from its EEPROM so we can load its drivers
          unsigned int loadedId = readEeprom(0x00, slot);
//          closeEeprom();

          switch (loadedId) {
            case breathalyzerModuleId:
              debug_println("Detected breathalyzer");
              carts[slot] = new BreathalyzerCart(slot);
              break;
            
            case frickinLaserModuleId:
              debug_println("Detected frickin' laser");
              carts[slot] = new FrickinLaser(slot);
              break;

            case flashlightModuleId:
              debug_println("Detected gratuitous flashlight");
              carts[slot] = new GratuitousFlashlight(slot);
              break;

            case thermometerModuleId:
              debug_println("Detected Thermodule");
              carts[slot] = new Thermodule(slot);
              break;

            case enviroModuleId:
              debug_println("Detected EnviroModule");
              carts[slot] = new EnviroModule(slot);
              break;

            case sdCardModuleId:
              debug_println("Detected SD card module");
              carts[slot] = new SDCardModule(slot);
              break;

            case testModuleId:
              debug_println("Detected top secret test module");
              carts[slot] = new TestCart(slot);
              break;

            case fluxgateModuleId:
              debug_println("Detected FLUXGATE MAGNETOMETER");
              carts[slot] = new FluxgateCart(slot);
              break;

            case lightSensorModuleId:
              debug_println("Detected APDS9960 breakout");
              carts[slot] = new LightSensorCart(slot);
              break;

            case oledModuleId:
              debug_println("Detected OLED on a string");
              carts[slot] = new OledCart(slot);
              break;

            case pulseOxModuleId:
              debug_println("Detected pulse ox");
              carts[slot] = new PulseOxCart(slot);
              break;

            default:
              debug_print("Cart ID "); debug_print(loadedId, HEX); debug_println(" not recognized");
              carts[slot] = new UnknownCart(slot);
              break;
          }

          if (carts[slot] != NULL) {
            carts[slot]->onInsert();
            if (carts[slot]->backgroundUpdateInterval > 0) {
              carts[slot]->lastBackgroundUpdateTimestamp = 0;
              carts[slot]->backgroundUpdate();
            }
          }

          switchStateTo(cartInsertInterstitial, slot);
          timeAwake = 0;
        }
      }
      else { // Cart ejection caused the last change
        if (carts[slot] != NULL) {
          debug_print("OK, cart "); debug_print(slot); debug_println(" is really ejected");
          if (activeApp != NULL && activeApp->owner.slot == slot) {
            debug_println("Closing its active app");
            //            switchStateTo(state, slot, true); // Switch to "not installed" screen, tell app it's being torn down because its cart was ejected
            switchStateTo(cartEjectInterstitial, slot, true);
            timeAwake = 0;
          }
          else switchStateTo(cartEjectInterstitial, slot);

          carts[slot]->onEject();
          delete carts[slot];
          carts[slot] = NULL;
        }
      }
    }
  }

  // Interpret battery monitor and CHRG pin
  // Clone volatile variables in case they change
  noInterrupts();
  byte chargeState = chargePinState;
  unsigned long highTime = chargePinHighTime;
  unsigned long lowTime = chargePinLowTime;
  unsigned long period = highTime + lowTime;
  interrupts();

  if (highTime != 0 && lowTime != 0 && (period < chargePinPeriod + chargePinPeriodJitter) && (period > chargePinPeriod - chargePinPeriodJitter)) {
    // A duty cycle of about 35KHz has been detected
    float dutyCycle = float(lowTime) / float(period) * 100.0f;

    // Read "error code" from duty cycle because Linear just has to be so fucking clever
    // ...making the pin both blink and machine-readable is pretty clever though
    if (((dutyCycle < ntcFaultDutyCycleLow + dutyCycleJitter) && (dutyCycle > ntcFaultDutyCycleLow - dutyCycleJitter)) ||
        ((dutyCycle < ntcFaultDutyCycleHigh + dutyCycleJitter) && (dutyCycle > ntcFaultDutyCycleHigh - dutyCycleJitter))) {
      // NTC fault detected
      if (batteryState != batteryNtcFault) {
        debug_println("Battery NTC fault detected?!");
        batteryState = batteryNtcFault;
      }
    }
    else if (((dutyCycle < badBatteryDutyCycleLow + dutyCycleJitter) && (dutyCycle > badBatteryDutyCycleLow - dutyCycleJitter)) ||
             ((dutyCycle < badBatteryDutyCycleHigh + dutyCycleJitter) && (dutyCycle > badBatteryDutyCycleHigh - dutyCycleJitter))) {
      // "Bad Battery" detected (not charging)
      if (batteryState != batteryChargeFault) {
        debug_println("Bad battery - not charging");
        batteryState = batteryChargeFault;
      }
    }

    // If neither fault was detected, something funny is going on. Ignore the error, it will be repeated in a few microseconds
  }
  else { // No duty cycle detected, charge pin indicates charge status
    if (chargeState) { // CHRG is active low
      if (micros() - chargePinChangeTimestamp > 150000 && batteryState != batteryNotCharging) {
        debug_println("Battery stopped charging");
        batteryState = batteryNotCharging;
        timeAwake = 0; // Ending charge wakes device up
        if (state == sleeping) switchStateTo(homeScreen);
      }
    }
    else if (micros() - chargePinChangeTimestamp > 150000 && batteryState != batteryCharging) {
      debug_println("Battery started charging!");
      batteryState = batteryCharging;
      timeAwake = 0; // Plugging in USB wakes device up
      if (state == sleeping) switchStateTo(homeScreen);
    }
  }

  // Update knob
  long newPosition = knob.read();
  int knobDelta = 0;
  if (newPosition != oldPosition && newPosition % 4 == 0) {
    if (newPosition > oldPosition) debug_println("Down!");
    else debug_println("Up!");

    knobDelta = (newPosition - oldPosition) / -4l;
    oldPosition = newPosition;
    timeAwake = 0; // Turning the knob keeps device awake but doesn't wake it up
  }

  // Update controls
  if (holdCutoffTime > 0) {
    if (!knobIsHeld && knobDownTimestamp > 0 && (millis() - knobDownTimestamp > holdCutoffTime)) {
      debug_println("Knob held!");
      knobIsHeld = true;
    }

    if (!homeHoldHandled && !homeIsHeld && homeDownTimestamp > 0 && (millis() - homeDownTimestamp > holdCutoffTime)) {
      debug_println("Home held!");
      homeIsHeld = true;
    }

    if (!buttonsHeld[0] && buttonDownTimestamps[0] > 0 && (millis() - buttonDownTimestamps[0] > holdCutoffTime)) {
      debug_println("Button 1 held!");
      buttonsHeld[0] = true;
    }

    if (!buttonsHeld[1] && buttonDownTimestamps[1] > 0 && (millis() - buttonDownTimestamps[1] > holdCutoffTime)) {
      debug_println("Button 2 held!");
      buttonsHeld[1] = true;
    }

    if (!buttonsHeld[2] && buttonDownTimestamps[2] > 0 && (millis() - buttonDownTimestamps[2] > holdCutoffTime)) {
      debug_println("Button 3 held!");
      buttonsHeld[2] = true;
    }

    if (!buttonsHeld[3] && buttonDownTimestamps[3] > 0 && (millis() - buttonDownTimestamps[3] > holdCutoffTime)) {
      debug_println("Button 4 held!");
      buttonsHeld[3] = true;
    }

    if (knobIsHeld || homeIsHeld || buttonsHeld[0] || buttonsHeld[1] || buttonsHeld[2] || buttonsHeld[3])
      timeAwake = 0; // Do not sleep while a button is held
  }

  // If we have an app active, the app gets first dibs on the controls.
  byte overriddenControls = 0x00; // Controls that have been consumed by the active app
  if (activeApp != NULL) {
    // First, assemble the masks.
    byte controlStates = 0x00; // TODO: Not sure what I intended to do with this. Figure that shit out
    byte clicks =
      knobJustClicked * knobMask +
      buttonsJustClicked[0] * button0Mask +
      buttonsJustClicked[1] * button1Mask +
      buttonsJustClicked[2] * button2Mask +
      buttonsJustClicked[3] * button3Mask +
      homeJustClicked * homeButtonMask;
    byte holds =
      knobIsHeld * knobMask +
      buttonsHeld[0] * button0Mask +
      buttonsHeld[1] * button1Mask +
      buttonsHeld[2] * button2Mask +
      buttonsHeld[3] * button3Mask +
      homeIsHeld * homeButtonMask;

    overriddenControls = activeApp->onControlEvent(controlStates, clicks, holds, knobDelta);
  }

  static bool overriddenButtons[] = {
    overriddenControls & buttonMasks[0],
    overriddenControls & buttonMasks[1],
    overriddenControls & buttonMasks[2],
    overriddenControls & buttonMasks[3]
  };

  // Interpret controls and switch states
  // There is a really long set of if-else blocks here.

  // Highest priority: Defense mode supersedes everything else.

  if (knobIsHeld && homeIsHeld) {
    if (state != defenseArming && state != defenseMode) {
      byte defenseCart = 0xFF; // TODO Prioritize types of defenses
      for (byte i = 0; i < 4; i++) {
        if (carts[i] != NULL && carts[i]->hasDefenseApp) {
          defenseCart = i;
          break;
        }
      }

      if (defenseCart < 4) switchStateTo(defenseArming, defenseCart);
      else {
        debug_println("No cart supports defense mode");
        switchStateTo(defenseArming);
      }
    }
  }

  else if (state == defenseArming) {
    // TODO Verify that defense mode is still available
    if (knobIsHeld) {
      if (!homeIsHeld && carts[activeCartSlot]->hasDefenseApp) switchStateTo(defenseMode, activeCartSlot);
    }
    else switchStateTo(homeScreen); // TODO Return to whatever state you activated defense mode from
  }

  else if (state == defenseMode) {
    if (!knobIsHeld && homeJustClicked) switchStateTo(homeScreen); // TODO return from whence ye came
  }

  // Priority 1: Quickfire apps

  else if (state == cartQuickfire) { // Note that all other buttons are ignored during quickfire
    if (!buttonsHeld[activeCartSlot]) switchStateTo(previousState, previousCartSlot);
  }

  else { // Not currently in quickfire
    for (byte i = 0; i < 4; i++) {
      if (buttonsHeld[i]) {
        switchStateTo(cartQuickfire, i);
        break;
      }
    }

    // Priority 2: Holding/pressing Home has special functionality.
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

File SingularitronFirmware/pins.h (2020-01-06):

#ifndef Pins_h_
#define Pins_h_

#define ble Serial2

#define buttonDriver 0x24
#define cartIOExpander 0x20

#define ledsPin 0
#define encoderB 1
#define fiveVoltSupply 3
#define sentralInterruptPin 4
#define displaySupply 5
#define vibes 6
#define displaySIO 7
#define displayReset 8
#define spiSCK 13
#define cart2gpio1 14
#define cart1gpio2 15
#define cart0gpio2 16
#define cart0gpio1 17
#define cart3gpio2 20
#define cart3gpio1 21
#define cart1gpio1 22
#define cart2gpio2 23
#define batteryMonitor A12
#define hotplugInterruptPin 24
#define buttonInterruptPin 25
#define displaySTB 26
#define displaySCK 31
#define encoderA 32
#define chargeStatusPin 33

const int cartGpioPins[4][2] = {
  {cart0gpio1, cart0gpio2},
  {cart1gpio1, cart1gpio2},
  {cart2gpio1, cart2gpio2},
  {cart3gpio1, cart3gpio2}
  };

#endif

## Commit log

2020-01-06 Added all the files
    Accidentally created the repo INSIDE the project folder instead of WITH it.
    Don't judge, you probably did it too.
    [Keycap 0.stl, Keycap 1.stl, Keycap 2.stl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]
2020-01-06 Added 3D design files
    [Enviro Module Cover Plate.f3d, EnviroModule.stl, Flashlight Front.stl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]
2021-06-07 Added some pics of the main unit PCB layout
2021-06-07 More Cartridges!!!
    Major overhaul done in preparation for the Singularitron episode!
    - Implemented breathalyzer, fluxgate, light sensor, OLED, and pulse oximeter cartridges
    - No code for Teensy module, I ran out of time
    - Pulse ox is EXTREMELY slow and buggy. Oximeter functionality is faked for now - this bug prevents the system from collecting data fast enough for sensible readings
    - Added system app for infinite boot messages
    [SingularitronFirmware.ino, fluxgate.h, gratuitousflashlight.h]

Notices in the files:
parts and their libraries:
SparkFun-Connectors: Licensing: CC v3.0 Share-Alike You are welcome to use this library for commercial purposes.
